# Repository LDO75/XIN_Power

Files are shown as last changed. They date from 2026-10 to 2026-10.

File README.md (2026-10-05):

# XIN Power

基于 **PY32F403 + SC8701** 的数控可调电源，面向当前 **V2补丁硬件**。

**3.2～32V · 0.1～8A过流设定 · 16点DAC校准 · 触摸屏 · 有线/蓝牙上位机**

最新控制版本为 **6.2.3**。本次开源打包修订标记为 **6.2.3-open.1**：设备协议/版本保持6.2.3，公开副本改用思源黑体生成的OFL字库，保留原交付包，二进制校验值与原6.2.3不同。

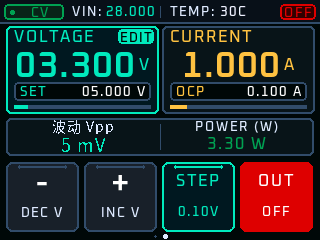
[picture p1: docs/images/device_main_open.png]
设备界面离线渲染预览


## 从这里开始

| 想做什么 | 入口 |
|---|---|
| 阅读完整开发文章 | [立创开源文章](docs/立创开源文章.md) |
| 查看当前硬件改动 | [V2补丁说明](hardware/README.md) |
| 编译、首次安装、升级 | [构建与下载](docs/构建与下载.md) |
| 做电压校准 | [校准与使用](docs/校准与使用.md) |
| 阅读开发顺序 | [开发历程](docs/开发历程.md) |
| 下载历史关键源码 | [历史版本索引](history/README.md) |
| 查看实际保护判据 | [当前固件说明](firmware/current/README_下载与校准.md) |
| 理解最新PI | [PI控制说明](firmware/current/docs/PI控制说明.md) |
| 实现自己的上位机 | [协议5](firmware/current/docs/WIRE_PROTOCOL_5.md) |
| 查看公开包验证结果 | [发布验证](docs/发布验证.md) |

## 当前完整工程

```text
firmware/current/
  01_Bootloader/     独立Bootloader（沿用5.9.3留存基准）
  02_Application/    当前APP、HAL/CMSIS、字库及生成工具
  03_Factory/        Bootloader与APP合并HEX脚本
  04_Recovery/       当前恢复路径说明
  05_PC_Tool/        Python/PySide6上位机、打包脚本、当前测试
  docs/             PI、协议、有线断链分析
  tests/            固件主机回归、界面渲染、RAM/栈预算
downloads/          开源构建APP/Bootloader/Factory、Windows上位机
hardware/           修改前V2原理图、补丁说明、外壳文件
history/            按版本排序的关键源码快照及校验信息
docs/               开源文章、开发历程、使用与编译说明
```

历史快照是本次整理后形成的归档，没有伪造原开发日期或把试验版统一称为实测稳定版。

## 硬件与功能边界

- R274=100kΩ；R314+R315=7.62kΩ；R316+R317=5.11kΩ；R292=1.8kΩ。
- 输出理想二极管MOS **D/S短接旁路**，软件按此状态适配。输出没有这一层防倒灌/隔离，关闭使能不等于物理断开端子。
- 8A是过流设定上限，软件不做恒流输出。输入过流阈值4.8A；没有完成32V/8A连续功率验证。
- INA读取目标500Hz，屏幕50Hz，常规回传默认25Hz；实际采样间隔需实测。
- “低频波动Vpp”是最近1秒采样极差，需要示波器另测高频纹波。
- 6.2.3仅在误差±100mV内PI微调；初始参数未完成实板带载整定。6.2.2历史节点可用于纯DAC控制对照。
- 原理图PDF为修改前参考，仓库尚未包含经过此次补丁更新的可编辑PCB/BOM/生产文件。

## 来源与许可

原电源方案参考立创开源作者 **cyxsnbb666** 的[Type-C可调电源项目](https://oshwhub.com/cyxsnbb666/typec-adjustable-power-supply-wi)。XIN Power由 **LDO75** 维护。

沿用本仓库现有 [GPLv3许可证](LICENSE)。第三方器件库及字体保留独立许可，详见 [THIRD_PARTY_NOTICES](THIRD_PARTY_NOTICES.md)。

## 反馈

报告问题时请注明：硬件阻值/输出级状态、固件与上位机版本、输入电源、设定和负载、万用表/示波器结果，以及故障现场。校准点和DAC读数对复现低压问题尤其有用。发布日志前请去除个人目录、设备标识或其他无关信息。

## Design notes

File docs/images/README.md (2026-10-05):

# 图片来源

- device_main_open.png、device_settings_open.png、device_settings_scroll_open.png：本次公开副本真实C端绘制代码的离线像素输出，中文采用XIN UI Heiti，不是实物照片。
- pc_smoke_623.png：原6.2.3 Qt离屏加载预览，不代表已连接设备或已实测回传速率。
- device_photo.jpg：开发者在讨论中提供的设备实物照片，拍摄于此次公开字体替换前，用于展示外观。
- off_oscillation_before_bypass.jpg：开发者提供的旁路前关断波动波形照片，只用于开发历程，不能用作当前旁路后的波形结果。

所有图像保留原始像素内容或由项目自身绘制代码生成，没有将离线渲染误标为实板验收。

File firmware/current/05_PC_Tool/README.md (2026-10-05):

# XIN Power Studio V6.2.3

运行EXE或run_windows.bat。左下角选择有线/无线、扫描系统端口、手动连接。扫描只枚举，连接只打开选定端口；旧协议4支持兼容文本，新版协议5二进制。

默认25Hz/40ms，可选10/5/50Hz。固件6.2.3修复了RATE设置不控制二进制遥测调度的问题。界面50Hz批量更新，中文状态日志显示最多5次/秒；完整收到的遥测仍写入记录及CSV。连接新版固件会配置40ms并读取STATUS，不更改电源输出。

Windows串口读写异常恢复同一有线端口，最多5次、每次间隔1.8秒，不重发旧的输出、设定或校准命令。改选端口/连接方式/断开取消恢复。普通命令确认超时会报告结果未知并继续接收数据。

校准16点，3.2–32V/0.1–8A，直接DAC调压，超过电流设定关断。校准保存和旧表迁移说明见根目录README_下载与校准.md。休眠在设备设置页选择。

当前版本测试（在tests目录）：python -X utf8 -m unittest test_620 test_622 test_623 -v。历史test_603等面向旧表/旧范围，不能直接作为本版验收。打包：build_windows.bat。
无硬件检查：XIN_Power_Studio_V6.2.3.exe --smoke-test --smoke-output preview.png，离屏启动并退出，不连接串口或启动实时控制接口。

新增全量程±100mV误差内PI微调，日志/诊断显示PI状态及误差；CSV29列。校准期间保持人工固定DAC；旧连续PID页面/接口不适用。控制参数及限制见根目录docs/PI控制说明.md。

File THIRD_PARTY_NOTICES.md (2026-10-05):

# 来源与第三方声明

## XIN Power

维护者：LDO75。沿用仓库已有GPLv3许可证，见根目录LICENSE。第三方文件的原有许可和版权不被根目录许可替代。

## 原电源工程参考

立创开源用户cyxsnbb666：[Type-C可调电源原工程](https://oshwhub.com/cyxsnbb666/typec-adjustable-power-supply-wi)。开发中参考其功率电路与STM32F1工程。当前公开目录是XIN Power的PY32工程及开发节点，没有重新打包原作者完整源码或替原作者选择许可。硬件参考图的来源关系在hardware/README及开发文章说明。

## 器件库

- Puya PY32F403 HAL和设备文件：保留各文件Puya/ST版权与BSD-3-Clause等原始声明；许可内容以文件头和所附文件为准。
- ARM CMSIS：保留Drivers/CMSIS/LICENSE.txt及相应文件版权说明。
- 上位机依赖PySide6/Qt、pyserial与Python：依赖库保留自身许可；requirements列出源码运行所需包，Windows可执行包的依赖通知按打包内容保留。

## 字体

- Oxanium：位图源自Oxanium，可重生成；原字体和OFL见02_Application/ThirdParty/Oxanium。
- 思源黑体：从Adobe官方source-han-sans的release提交`a4f7cf94edfb9d7ffbdfc4841de276358bd7e0f2`获取未修改的`SubsetOTF/CN/SourceHanSansCN-Regular.otf`。原字体及OFL见02_Application/ThirdParty/SourceHanSans。官方来源：[Adobe仓库](https://github.com/adobe-fonts/source-han-sans)、[OFL文本](https://github.com/adobe-fonts/source-han-sans/blob/release/LICENSE.txt)。
- 公开副本使用派生位图 **XIN UI Heiti**，由Tools/generate_heiti_font.py生成，派生位图仍适用OFL-1.1。没有把OFL字体更改为GPL许可。
- Windows SimHei只存在于原私有交付版本中；本次公开当前/相关历史副本的字库均替换为上述OFL派生位图，没有分发Windows字体文件。

历史节点添加的字体许可证和生成资源在索引中标注；保留原始包SHA256用于辨别本次公开整理与原交付快照的差异。

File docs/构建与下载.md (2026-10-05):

# 构建与下载

## 1. 工程顺序与工具

从`firmware/current`开始：01_Bootloader → 02_Application → 03_Factory → 04_Recovery说明 → 05_PC_Tool。

- 已使用工具链：Keil MDK / Arm Compiler 6.24；Puya.PY32F4xx_DFP.1.0.8；实际芯片PY32F403C1DT6，工程设备组PY32F403xD。
- Python 3环境；上位机依赖见05_PC_Tool/requirements.txt，安装pyserial和PySide6_Essentials。
- 字库重生成需Pillow；随源码提供OFL思源黑体、Oxanium字体及生成工具。
- 固件主机检查使用GCC和PowerShell；Keil链接后的RAM/栈预算需Python检查。离线检查不打开串口。

## 2. 内部Flash与外部Flash

| 区域 | 地址与长度 |
|---|---|
| Bootloader | 0x08000000，0x8000字节 |
| APP | 0x08008000，0x58000字节 |
| 内部Flash终点 | 0x08060000 |
| RAM | 0x20000000，0x10000字节 |
| W25暂存/回退 | 0x00000000 / 0x00080000，各0x80000 |
| 升级元数据 | 0x00100000 / 0x00101000，各4KiB |
| 设置/校准保留区 | 0x01FFC000～0x01FFFFFF |

独立Bootloader来自留存的5.9.3完整工程，升级布局/硬件ID/元数据schema沿用当前APP的兼容定义，比较结果见发布验证。未把旧Factory HEX当作新版本完整镜像。

## 3. 编译

已有Bootloader时只需要APP。在工程目录运行（按本机路径修改参数）：

```powershell
./build_firmware.ps1 -KeilPath 'C:/Keil_v5/UV4/UV4.exe' -Python python
```

也可分别用Keil打开：

```text
01_Bootloader/MDK-ARM/XIN_Power_BL.uvprojx
02_Application/MDK-ARM/XIN_Power.uvprojx
```

Bootloader输出`01_Bootloader/MDK-ARM/Objects/XIN_Power_BL.hex`；APP输出`02_Application/MDK-ARM/Objects/XIN_Power.hex`。APP脚本会检查零错误/零警告及栈预算。默认下载算法需选择官方器件包对应容量，不要用其他容量的通用算法代替。

公开中文位图已经生成。如需重生成：

```powershell
python 02_Application/Tools/generate_heiti_font.py
python 02_Application/Tools/generate_oxanium_font.py
```

## 4. 空片安装与APP更新

空片先生成完整合并HEX：

```powershell
python 03_Factory/make_factory_hex.py 01_Bootloader/MDK-ARM/Objects/XIN_Power_BL.hex 02_Application/MDK-ARM/Objects/XIN_Power.hex 03_Factory/XIN_Power_FACTORY_SWD.hex
```

脚本检查HEX校验、BL/APP地址、向量表及重叠。SWD首次安装下载Factory镜像，核对运行后再做校准。

**已有兼容Bootloader的板子只刷APP。** APP基址0x08008000，不覆盖前32KiB。保留W25Q256；不要为了升级执行全片擦除、修改读保护或CAL RESET。用上位机在线升级时选择APP HEX/BIN，等待上传、校验、应用和重启确认；BL搬运阶段保持供电。

## 5. 上位机源码和打包

进入05_PC_Tool，运行`run_windows.bat`，或安装requirements后按该脚本的Python入口运行。打包用`build_windows.bat`，其中PyInstaller等构建工具由脚本管理。

已有Windows EXE也放在downloads目录；与源码同为6.2.3。EXE不会因为本次固件换字体而自动修改通信版本。实时接口设置文件只在需要本机接口时使用，不含固定端口和个人会话数据。

## 6. 检查入口

```powershell
./tests/run_620_checks.ps1
```

上位机在05_PC_Tool/tests目录执行：

```powershell
python -X utf8 -m unittest test_620 test_622 test_623 -v
```

固件检查会产出UI像素预览和数据包向量，上位机测试使用它们。package_623.py为原交付包校验入口，其对原构建日志和文件布局有固定要求；开源包使用仓库发布说明及SHA256SUMS，不应直接套用原打包脚本声称验证通过。

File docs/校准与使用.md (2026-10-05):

# 当前版本校准与使用

## 首次使用

1. 按硬件补丁说明核对R316、R292及输出理想二极管旁路。
2. 使用稳定输入。28V PD供电要确认适配器与诱骗协议支持该档位；小电流自动休眠会影响调试。
3. 有线/无线手动选定系统串口，连接后核对固件6.2.3、硬件V2、协议5、3.2～32V范围。
4. 首先读取原校准表，不执行CAL RESET或全片擦除。
5. 新阻值/新输出通路下，空载用可信万用表重新确认各点，再接实际负载。

## 校准

16点：3.2、3.3、3.5、3.8、4、4.2、5、7.2、8.4、9、12、18、20、24、28、32V。

选择点位后手动调DAC。升压降低DAC码，降压提高DAC码；接近目标时单码调整。输入**万用表实测值**，点击采集并保存，等设备确认及读回一致后再继续。每个点独立生效，保存后输出关闭。

校准期间PI关闭，DAC固定。若DAC没有变化而万用表电压继续变化，先检查硬件工作点和参考供电，等待真实稳定再采集。没有“只要按钮成功就代表输出稳定”的假设。

schema5按名义电压迁移旧schema3/4匹配点。硬件标记0x4991对应当前阻值；不兼容阻值配置的表不能直接沿用。旧表12个匹配点可保留，新增3.2/3.5/3.8/4.2V需实测。

## 常用功能

- 主界面设定电压、过流阈值、开启/关闭输出；右滑进入左侧设置页。
- 超过电流阈值关断锁存，清除故障不会自动开启。
- 默认屏幕1分钟休眠，可选关闭/30/60/120/300/600秒；休眠不停止供电。任意触摸唤醒，下一次触摸才执行操作。
- 遥测默认25Hz；中文状态摘要最多5条/秒只是显示节流，实际数据以完整记录/速率统计为准。
- 输出关闭仍显示真实残压。Vpp是低频采样极差；切换设定后重新等待稳定并收集1秒窗口。

## PI边界

6.2.3在3.2～32V全范围、误差不超过±100mV时PI微调，超范围暂停并保持当前码。校准/换设定/关闭/故障会重置；只补偿INA测量点上的电压，不补偿该点之后的外部线损。

参数Kp0.20、Ki2.00/s、D0为待实板整定的初始值。DAC每码约14.33mV，不能承诺任意目标1mV精度。持续大于100mV的压降不在当前外环纠正范围。

## 实测建议

优先记录3.2/3.3/5V空载与加载/卸载，再扩展到12/24/32V。记录输入、负载、目标、万用表、电压波形、DAC和PI状态。短路/过流验收需量到真实电流及关断时刻，INA软件读取不能代替微秒级硬件比较器。高功率测试要同时记录输入限流与热状态。

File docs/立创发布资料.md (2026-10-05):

# 立创开源新项目发布资料

## 可直接填写

- 标题：**XIN Power｜PY32F403＋SC8701 3.2～32V数控可调电源**
- 摘要：基于PY32F403与SC8701的V2补丁电源，支持3.2～32V、0.1～8A过流设定、16点DAC校准、触摸屏、有线/蓝牙上位机和在线升级。本文公开完整工程及关键历史版本，记录低压调试、SRC供电漂移、输出级旁路、500Hz测量调度、二进制DMA通信和小误差PI微调的开发过程。
- 标签：数控电源、SC8701、PY32F403、INA226、Type-C、触摸屏、蓝牙、开源硬件。
- 源码链接：https://github.com/LDO75/XIN_Power
- 正文：[立创开源文章.md](立创开源文章.md)。
- 原项目来源：https://oshwhub.com/cyxsnbb666/typec-adjustable-power-supply-wi

## 附件对应

| 内容 | 仓库位置 |
|---|---|
| 当前完整源码 | firmware/current，或源码完整ZIP |
| APP/Bootloader/工厂HEX | downloads |
| Windows上位机 | downloads中的part1、part2及merge_pc_tool合并脚本；合并后为XIN_Power_Studio_V6.2.3.exe |
| 原理图PDF | hardware/V2_schematic_before_patch_2026-09-13.pdf |
| 必读硬件补丁 | hardware/README.md |
| 外壳模型 | hardware/enclosure |
| 历史关键源码 | history |
| 图片 | docs/images，caption需注明离线渲染或实物 |

原理图是修改前参考，平台若要求可生产PCB/BOM附件，当前材料尚未包含更新后的EDA工程、BOM、Gerber。不要把参考PDF上传成已修改完成的生产板文件。

## 图片顺序和图注

1. 设备主界面：离线执行真实LCD绘制代码的像素预览。
2. 中文设置页：公开OFL字库的离线预览，非拍摄照片。
3. 休眠/滚动设置：离线预览，标出休眠入口。
4. 上位机：Qt离屏加载预览，不作为实机通信/回传性能证据。

本次文章正文和附件在本地/GitHub准备后，平台项目是否已保存/发布，以真实项目链接和平台返回为准。没有项目链接时不能将“文档已准备”写成“已在立创发布”。

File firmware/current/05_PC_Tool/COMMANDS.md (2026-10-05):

# V6.2.0 命令

新上位机将操作编码为协议5二进制包；普通串口助手先发送INFO可进入兼容文本模式。完整字节约定见[通信协议](../docs/WIRE_PROTOCOL_5.md)。

| 操作 | 参数/行为 |
|---|---|
| INFO / STATUS / DIAG | 版本、状态、链路诊断，只读 |
| SET V mV | 3200–32000mV，已保存点映射DAC，无PID |
| SET I mA | 100–8000mA，过流关断阈值，无恒流环 |
| OUT ON / OFF | 开启/关闭；故障锁存时先CLEAR |
| CLEAR | 清除故障，保持输出关闭 |
| CAL POINT GET / GET id | 表概况/单点；schema5，id=0–15按电压升序 |
| CAL POINT START id | 手动DAC校准并开启输出，保留电流阈值 |
| CAL POINT STEP -5/-1/1/5 | 直接调码；负码升压、正码降压 |
| CAL POINT STATUS | 活动点/DAC/电压/ready，ready仅表示DAC已写入 |
| CAL POINT CAPTURE mV | 保存万用表值和DAC；先OFF再写Flash，上位机读回确认 |
| CAL POINT STOP | 关闭输出，恢复此前设定，不保存未采集数据 |
| CAL GET / RAW | 测量系数/原始读数 |
| CAL SET V/I gain offset / SAVE / RESET | 输出关闭时修改测量系数/保存/恢复默认；正常升级不要RESET |
| LOG ON / OFF | 遥测开关，故障事件仍回传 |
| LOG RATE 20 | 协议5固定20ms；文本兼容模式最短100ms |
| FW STATUS / BEGIN / DATA / END / APPLY / ABORT | 升级页管理，旧Bootloader兼容 |
| PING / HELP | 连通性/帮助 |

点位：3.2、3.3、3.5、3.8、4.0、4.2、5、7.2、8.4、9、12、18、20、24、28、32V。每个点独立保存后生效，不必全部完成。保存检查实测电压区间顺序和Flash写入，不以贴近目标或INA一致作为采集限制。

START所在通道持有校准，STEP/CAPTURE只允许该通道；其他通道可STOP或关闭输出。普通设定、测量校准、升级须先STOP，Flash忙时返回错误。超时不等于保存成功，应读取状态确认。

V6.2.0没有PID命令、恒流控制、独立低压SHORT判据。协议号36保留，当前APP不提供REBOOT命令。

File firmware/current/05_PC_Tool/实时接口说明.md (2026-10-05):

# V6.2.0本机实时接口

把realtime_settings.json（enabled=true）放在EXE旁边。仅监听127.0.0.1，启动后地址和随机令牌写入live_api.json；不会自动连接设备。请求需Authorization: Bearer令牌。

- GET /v1/state：最新解算遥测、数据年龄、设备信息、epoch。
- GET /v1/events?after=游标：完整遥测、ACK、错误、故障等增量事件。
- POST /v1/voltage：mv为3200–32000整数。
- POST /v1/output：on为布尔值。
- POST /v1/telemetry-rate：ms只能为20，固定50Hz。
- POST /v1/connection：connected为布尔值，只操作上位机当前选择的端口。

POST需当前epoch。HTTP202表示排队，不等于设备执行成功；需等待对应ACK和后续状态。手动校准期间不允许该接口修改普通输出或电压。PID接口在直接DAC固件不可用。

JSONL通过后台线程缓冲写入，实际路径以live_api.json的record字段为准。vfast为原始校准后电压，vraw为未校准电压，iraw为未校准电流，vpp为最近1秒低频波动，hz/maxgap为内部完整采样实测频率/间隔，seq/samplet为完整采样序号/时间。cegpio是MCU引脚读回，不是SC8701脚模拟实测；dw/dwt为成功DAC写入计数/时间。

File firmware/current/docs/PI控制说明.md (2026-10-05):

# 6.2.3小误差PI控制说明

## 用户确认的边界

范围3.2–32V；误差进入±0.1V才启用PID微调。实现采用PID的PI形式，D项0。测量点仍是现有输出INA226，不能补偿测量点之后的外部接线压降。正常起步使用现有16点校准映射，手动校准仍固定DAC。

| 状态 | DAC行为 |
|---|---|
| 开启输出/改设定 | 应用新的校准映射码，重置积分 |
| 有效新样本且误差≤100mV | PI微调，误差≤8mV时保持 |
| 误差>100mV | 保持已应用码，暂停PI；回到范围无突变恢复 |
| 样本失效或dt>20ms | 暂停PI、不把停顿时间累积进积分 |
| 关闭/故障 | 先关闭CE，再停车DAC；PI重置 |
| 手动校准 | 固定人工DAC，PI关闭，不自动学习/改校准表 |

## 方程与实现

e=设定电压−INA校准后快速电压（mV）。当地DAC斜率g（mV/码）用同一校准映射附近区间估计，端点用单边区间，无有效斜率则使用原电阻公式。

P=−Kp×e/g；I候选=I−Ki×dt×e/g；DAC连续命令=映射基准+I候选+P。负号对应本硬件DAC升高使输出降低。

Kp=0.20，Ki=2.00/s，Kd=0。每个新样本最多计算一次，目标500Hz，采样与限流判断先于PI。LCD绘制让出前台时也服务PI，无阻塞中断I²C。样本序号不变不重复积分。
进入误差范围时令I=已应用DAC−基准−P，防止比例项造成切换跳变。DAC裁剪到0–4095、连续命令限制在当前码±1内，再反算I；写入失败不提交积分。整数码需连续命令偏离当前至少0.65码才变化；写入至少间隔10ms，减少量化来回跳码。

按电阻理论每码约14.33mV，实际采用校准区间估计，不能承诺1mV调节分辨率。8mV死区和0.65码滞回用于限制噪声/量化引起的跳码，仍需实际噪声与负载验证。没有±100mV总补偿限制，只有用户指定的误差准入；DAC饱和时无法保证回到目标。

## 理论与模型的范围

把SC8701已经闭环的DAC到输出响应近似成归一化一阶G(s)=1/(1+τs)，软件PI为C(s)=Kp+Ki/s。连续模型特征式为τs²+(1+Kp)s+Ki=0，τ>0时这些参数满足二阶稳定条件；τ=200ms时阻尼约0.95。该推导不包含实际功率级的额外极点、轻载模式切换、采样/I²C延迟和MOS寄生。

真实C控制器另在216个离散一阶模型组合测试：3.2/17.6/32V，τ=5/20/80/200ms，纯延迟0/10/20ms，执行器增益0.5/1/1.5倍，±80mV负载扰动、±2mV测量噪声，加载后卸载。结果及最大末端误差见验证记录/model_summary_623.json；这是假设模型的结果，不是SC8701实机测量，不能据此承诺所有负载稳定或无过冲。

数字环路的采样和执行延迟限制可实现带宽；软件外环应根据实测动态调整，500Hz计算频率不代表500Hz控制带宽。参考：[Microchip数字控制实现](https://developerhelp.microchip.com/xwiki/bin/view/applications/power/digital-power-converter-basics/implementation-of-a-control-loop/)、[TI数字环路设计](https://www.ti.com.cn/cn/lit/pdf/slua622)。

正常PI写码使用同一映射基准作为Vpp调压事件标识，因此不会每次微调都清空1秒波动窗口。换设定、开关输出、手动DAC步进仍按原稳定准入冻结/重开窗口，PI本身的真实波动不会被普通微调事件隐藏。

## 建议实测记录

先在3.3V、5V、12V、32V分别观察空载、加载、卸载，记录vfast、误差、DAC、PI状态、波动和采样间隔。重点区分误差越过100mV导致的暂停与闭环参数振荡；前者是本版明确的准入规则。大于100mV压降不会自动纠正，不应靠提高Ki解决。参数未经过该板实测整定。

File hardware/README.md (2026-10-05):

# V2硬件基准与补丁

当前源码用于PY32F403C1DT6、SC8701、MCP4725/REF3030、LMV321、双INA226、W25Q256、ST7789/CST836的V2板。功率MOS曾与原作者不同，输出理想二极管MOS实装型号曾为AGM6014A；最终该级D/S被旁路。

## 最终基准

| 器件/网络 | 当前配置 |
|---|---|
| R274，Vout至FB | 100kΩ |
| R314+R315，FB至地 | 7.5kΩ+120Ω=7.62kΩ |
| R316+R317，FB至缓冲输出 | 4.99kΩ+120Ω=5.11kΩ |
| R292泄放 | 实装1.8kΩ |
| DAC | 3.000V参考，4096码比例 |
| 输出理想二极管 | MOS D/S短接旁路，当前功率通路不依赖此级 |

早期曾从输入28V向MX16171的SRC飞线供电，用于解决输出侧供电下的低压/漂移问题。这是历史排查方案，不是当前版本必须保留的供电要求。旁路之后应避免仍连接控制器的残留供电/栅极网络干扰其他节点；具体拆改以实板连线为准。

## 图纸和外壳文件

- [V2修改前原理图](V2_schematic_before_patch_2026-09-13.pdf)：来源为开发者提供的2026-09-13 PDF。R316、R292及输出级请以上表和实装为准。
- [外壳目录](enclosure/)：开发者提供的STEP与3MF，文件保留原中文名称。打印材料、尺寸公差、散热开孔和端子位置需根据实物确认。

本次已收集到原理图PDF及外壳模型；**未收集到完成当前补丁的可编辑EDA工程、BOM和Gerber**。因此这些文件不能作为“已完成生产包”使用。

## 输出关断与反向供电

CE关闭的是SC8701功率级。输出电容和板内供电/测量路径仍可能留下残压，固件回传实际测量值，不把关闭状态强制显示为零。旁路后的输出缺少原理想二极管提供的反向隔离；外部电池、另一个带电电源、并联输出需要专门的隔离/反向保护设计。

## 理论DAC关系

Vout=Vfb(1+Ru/Rd+Ru/Ri)−Va·Ru/Ri。按Vfb=1.22V估算：

- 4.99kΩ配置：Vout≈41.10−19.57Va，每码约14.33mV。
- 7.5kΩ配置：Ri=7.62kΩ，Vout≈33.24−13.12Va，每码约9.61mV。

这只表示反馈网络的直流数学关系，不能证明运放共模范围、功率级动态或输出后级都正常。更换阻值后需重校，不能混用旧硬件标记的DAC表。

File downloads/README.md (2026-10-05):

# 当前公开构建下载

## 6.2.3-open.1

设备仍报告6.2.3/协议5。本次公开APP使用思源黑体派生位图，与原6.2.3私有交付镜像HASH不同，控制参数/硬件基准不变。

| 文件 | 用途 |
|---|---|
| XIN_Power_V6.2.3_OPEN1_APP_USB_BT.hex / .bin | APP，基址0x08008000，已有Bootloader时选它 |
| XIN_Power_BL_BASE_5.9.3.hex | 留存5.9.3基准Bootloader在公开目录重新编译的镜像 |
| XIN_Power_V6.2.3_OPEN1_FACTORY_SWD.hex | 本次Bootloader与APP合并，空片SWD首次安装 |
| XIN_Power_Studio_V6.2.3.part1 / .part2 | 原6.2.3 Windows上位机的两个分卷，与当前协议兼容 |
| merge_pc_tool.cmd / merge_pc_tool.ps1 | 合并分卷，生成并校验 XIN_Power_Studio_V6.2.3.exe |
| XIN_Power_V6.2.3_OPEN1_FullSource.zip | 当前完整工程、构建脚本与许可；与源码目录对应 |
| SHA256SUMS.txt | 本次下载文件校验 |

GitHub文件页面点击Download raw即可下载。已有BL只更新APP，不要全片擦除。完整说明见docs/构建与下载及发布验证。

Windows上位机：下载 `.part1`、`.part2`、`merge_pc_tool.cmd`、`merge_pc_tool.ps1`，放在同一个文件夹，双击 `merge_pc_tool.cmd`。合并结果的SHA256必须是 `26b0bc8aff796a220c3d64fe7aa41e574d7a40b57a84bfd3dafa50d0bbba67cf`。分卷仅用于绕过上传接口的单次传输限制，合并后的程序与原交付EXE完全一致。

Windows程序基于Python3.12、PySide6/Qt6.8.3、pyserial3.5及PyInstaller6.16打包。依赖许可文本在licenses；上位机源码和打包脚本可用于重建/替换依赖，Qt源代码入口为https://code.qt.io/qt/。本次上传没有重新运行实机串口。

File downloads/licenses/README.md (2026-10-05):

# Windows上位机依赖许可

本次WindowsEXE沿用6.2.3交付，源码与构建脚本在firmware/current/05_PC_Tool。

| 组件 | 版本/来源 | 许可及源码入口 |
|---|---|---|
| Python | 3.12.7，打包构建环境 | Python-3.12-LICENSE.txt；https://www.python.org/downloads/source/ |
| PySide6 / Shiboken6 / Qt | 6.8.3 Essentials | LGPL-3.0.txt及GPL-3.0.txt；https://code.qt.io/pyside/pyside-setup/；https://code.qt.io/qt/ |
| pyserial | 3.5 | pyserial-LICENSE.txt；https://github.com/pyserial/pyserial/tree/v3.5 |
| PyInstaller | 6.16.0 | pyinstaller-COPYING.txt，含Bootloader例外；https://github.com/pyinstaller/pyinstaller/tree/v6.16.0 |

许可文本分别从构建环境、GNU官方许可页面和上述版本的PyPI源码分发包取得。可通过公开上位机源码及PyInstaller打包脚本重新构建并替换库；完整许可条件以各文本为准。运行程序不代表许可变更。

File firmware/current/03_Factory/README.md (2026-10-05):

# 首次安装合并HEX

先编译01_Bootloader和02_Application，再运行make_factory_hex.py。地址、校验和、向量表和重叠检查通过后才会生成Factory镜像。

已有Bootloader只更新APP；Factory用于空片首次SWD安装或明确需要重装的情况。不要为了普通升级清空W25Q256或已有校准。

公开包downloads中的Factory来自本次重建BL及思源字库APP合并。文件检查通过不等于实机首次安装/掉电恢复已验收，详见docs/发布验证.md。

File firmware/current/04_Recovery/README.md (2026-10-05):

# 恢复入口

已有Bootloader时使用当前APP；空片使用03_Factory合并脚本。历史5.8.6恢复HEX对应旧硬件和旧存储格式，不作为当前V2补丁板的默认恢复镜像。故障记录和校准数据应先备份。

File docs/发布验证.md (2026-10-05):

# 6.2.3-open.1公开副本验证

本次只整理、构建和验证公开副本，没有连接电源串口、烧录或执行负载试验。原6.2.3交付包保留。

## 本次副本差异

- 中文位图由Windows SimHei改成OFL思源黑体派生的XIN UI Heiti；提供原字体、许可、固定上游提交、生成脚本和派生位图声明。
- 补入留存5.9.3基准Bootloader完整源码及工厂合并脚本；APP/BL的OTA布局文件去除换行形式差异后完全一致。
- 当前完整工程按01～05目录提供；第三方Oxanium资源和许可补齐。
- 历史关键节点公开归档标明原始包/公开包HASH、硬件前提及整理差异。6.2.2同样换OFL中文位图后重新构建；其他节点提供留存的对应APP。
- 未修改6.2.3控制逻辑、保护阈值、协议5字段或校准存储布局。设备版本仍为6.2.3，文件名OPEN1用于区别公开构建。

## 已完成

| 检查 | 结果 |
|---|---|
| 当前APP完整Keil重编译 | 0 errors / 0 warnings |
| 当前Bootloader重编译 | 0 errors / 0 warnings |
| Keil项目引用完整性 | BL、APP全部FilePath在公开完整源码内可解析 |
| APP RAM/栈预算 | RAM55376/65536；栈8192；静态最大3620；另留2048后余量2524 |
| 公开APP图像 | 126992字节；基址0x08008000；包含6.2.3/proto5标识 |
| 工厂合并 | BL/APP地址、HEX校验、向量表和非重叠检查通过 |
| 当前固件C回归 | 校准/迁移/Flash、保护/优先电流、500Hz新样本、协议/DMA/重试、Vpp、UI清黑/休眠及PI边界通过 |
| 假设一阶模型 | 原控制器216组组合通过；未扩展为实际SC8701电路模型 |
| 当前上位机源码检查 | test_620/test_622/test_623，共19项通过 |
| 思源中文界面 | 重新渲染并目视检查设置页，文字、布局与按钮正常；切页/休眠回归通过 |
| 6.2.2公开副本 | Keil零错误零警告、C回归通过；纯DAC对照节点 |
| 全部公开ZIP | ZIP校验通过，含逐文件SOURCE_SHA256 |

APP SHA256：`5a403d5a24ecfcac26b74bdd554b5de0ee46a06ca9b34f3953439dbce5b1ba1c`。

Bootloader从留存工程重新构建。Factory只是本次重建镜像的地址检查与合并，没有据此宣称空片首次下载、升级搬运掉电或回退全过程经过本轮实机验收。上位机EXE沿用原6.2.3交付，源码测试本轮重新运行。

## 仍需实测

- 3.2/3.3V启动、加载/卸载、DAC量化波动、PI整定及过冲恢复。
- 输入限流条件下的输出功率、持续温升、不同负载的稳定性。
- 真实短路/过流关断延迟、板上CE相关电路和功率级硬件响应。
- 同时切页、触摸、通信时的最大采样间隔及25Hz回传达标情况。
- 理想二极管旁路之后的关断残压及外部反向供电路径。

离线模型、渲染和源码检查验证实现及边界行为，不能替代以上测量。静态RAM/栈预算也不是实机高水位测量。

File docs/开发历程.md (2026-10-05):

# 开发历程与版本边界

按实际留存的发布记录及开发者实板反馈整理。表格描述阶段目标，不把一次离线检查或一次空载校准当成全面验收。未恢复到的更早版本和中间小修订不虚构源码节点。

| 版本/阶段 | 变化与原因 | 当时边界 |
|---|---|---|
| 5.8.6恢复参考 | 早期SWD恢复文件、旧上位机 | 旧硬件/存储前提，不是当前默认恢复包 |
| 5.9.3 | 留存完整BL、APP、Factory、Recovery、PC；风扇迟滞和通信调度改进 | 原输出控制，尚未完成后来的低压/输出级修改 |
| 5.9.4～5.9.9 | 在既有升级、校准与通信框架上连续迭代 | 留存记录可追溯，此次未把每个小版本都打包 |
| 6.0.0～6.0.1 | 低压启动与16点校准，增加3.6/3.9/4/4.5V等点 | 仍有稳定和保存门槛；低压异常待定位 |
| 6.0.2 | 加强校准稳定窗口/漂移判定 | 使用复杂，产生校准难保存的反馈 |
| 6.0.3 | 直接人工DAC→实测值→保存→插值 | 按当时要求主要保留过流；不作为当前保护完整版本 |
| 6.0.4 | 修复3.6V点被旧DAC顺序校验拒绝保存 | 低压跳变仍需排查硬件 |
| 6.0.5 | 持续PID试验 | 为比较响应而做的试验版 |
| 6.0.6 | 上位机PID参数页 | 参数需在稳定输入、明确负载条件下整定 |
| 6.0.7 | 本机实时读取/控制接口 | 便于调参；本次未把此试验节点作为默认公开控制版 |
| 6.0.8 | R316=4.99kΩ、直接DAC映射；SaveDiag/SaveFix1/UIFix修复Flash保存、读回、上位机协调 | 同一版本号下有多个诊断/修复变体，本次选SaveFix1_UIFix |
| 6.1.0 | 输出理想二极管SRC输入侧供电补丁 | 关闭残压与规律波动仍有实板反馈 |
| 6.1.1 | 2～32V、R316=7.5kΩ，恢复基础保护 | 2V校准空载触发SHORT的判据有问题 |
| 6.1.2 | 短路资格判定修正 | 继续排查误判 |
| 6.1.3 | 短路改走同一立即过流路径，去掉低电压独立SHORT判据 | 有效电流越限关断，仍依赖采样时延 |
| 6.1.4 | 目标1kHz读取 | 实板触摸和刷新受影响，后续调整为500Hz |
| 6.1.5 | R316=4.99kΩ匹配理论DAC与硬件标记 | 当时2～32V/17点设计不是当前最终范围 |
| 6.2.0 | 最终3.2～32V、8A设定；500Hz采样/50Hz屏幕；16点；协议5、DMA、中文设置与PC重排 | 输出级仍处于随后调整的阶段；回传默认随后改25Hz |
| 6.2.1 | 输出理想二极管MOS D/S旁路；切页清黑/顶部栏恢复；Vpp换设定后重建窗口 | 开关仍是CE使能，不是物理输出隔离 |
| 6.2.2 | 屏幕休眠、回传25Hz、RATE生效、有线同端口恢复 | Windows访问拒绝的设备/驱动根因未唯一定位 |
| 6.2.3 | 全量程±100mV误差内PI，死区、滞回、单码节流、积分和门控切换处理 | 最新试验参数有离线模型/代码检查，尚待带载整定 |
| 6.2.3-open.1 | 本次公开目录、文档、历史索引、OFL中文字体及重建镜像 | 控制/协议仍6.2.3；字体不同，二进制HASH不同 |

## 四条调试主线

### 校准

从“目标/稳定条件限制”回归“人工DAC与万用表实测关系”。随后修复单点资格、Flash保存、读回、上位机显示以及不同schema/点位ID迁移。R316变更必须同步曲线标签。

### 低压硬件

3.5V附近跳变 → 分段观察前后电压 → 反馈阻值与DAC表匹配 → SRC供电方式改变后漂移不同 → 断开SRC周期波动消失 → 最终旁路该输出级。用户提供的测量支持缩小故障范围，没有证明理想二极管芯片内部唯一机制。

### 保护与调度

误判低电压空载SHORT → 以实际过流为短路关断依据 → 保留输入欠压/过压/过温/监测失联 → 1kHz影响交互 → 500Hz采样、电流优先、SPI让出服务、DMA发送。

### 产品交互

屏幕主界面精简 → 设置页中文 → 清黑/顶栏重绘 → Vpp稳定后重新统计 → 屏幕休眠不改变输出 → PC手动选连接方式、中文日志、后台批处理 → 默认25Hz与有限同端口恢复。

## 最新验证的解读

离线C检查覆盖保护、存储、协议、重试与UI状态；Python检查覆盖数据包、命令、升级状态机、串口选择/恢复和页面加载。假设一阶模型用于验证控制实现的边界行为，不是实际SC8701/MOS电路的SPICE模型。

实板曾完成不同节点的校准与低压观察；最新公开字体构建没有因此被标为“完成32V8A、所有负载、长期老化验收”。当前范围和硬件状态请以README/硬件补丁为准。

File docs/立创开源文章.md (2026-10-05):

# XIN Power：从低压调试到完整软硬件闭环的 3.2～32V 数控电源

> 基于 PY32F403 与 SC8701 的 V2 补丁硬件项目，支持触摸屏、有线/蓝牙上位机、16点电压校准、过流关断、在线升级，以及小误差区间的 PI 电压微调。本文记录当前方案，也保留开发过程中走过的弯路。

## 一、为什么做这台电源

做单片机和各种小板子时，最常用的功能其实很直接：设定电压、限制异常电流、观察功率，出问题时及时关闭输出。3.3V尤其重要，因为这正是很多单片机的工作电压。

XIN Power的开发经历了多轮固件、上位机和硬件修改。最耗时的问题集中在低压区：3.6V校准时，输出从约3.5V突然跳到4V；部分阻值配置下，2V目标始终降不下来；关闭输出后，还能看到规律性的小幅电压波动。期间尝试过直接DAC映射、连续PID、反馈电阻调整、理想二极管供电修改，以及采样和任务调度优化。

最后根据当前V2板子的实测表现，把公开版本的调压范围确定为 **3.2～32V**，电流设定上限 **8A**。这个取舍保留了3.3V应用所需的低压区，也让软件参数与当前硬件保持一致。

项目在原开源电源方案的基础上继续开发。原项目作者为立创开源用户 **cyxsnbb666**，原工程链接：[Type-C可调电源原项目](https://oshwhub.com/cyxsnbb666/typec-adjustable-power-supply-wi)。感谢原作者提供功率级设计和源码参考。XIN Power的PY32工程、上位机、校准流程及后续补丁在此基础上迭代，第三方器件库和字体保留各自许可声明。

完整源码与版本索引：[LDO75/XIN_Power](https://github.com/LDO75/XIN_Power)。

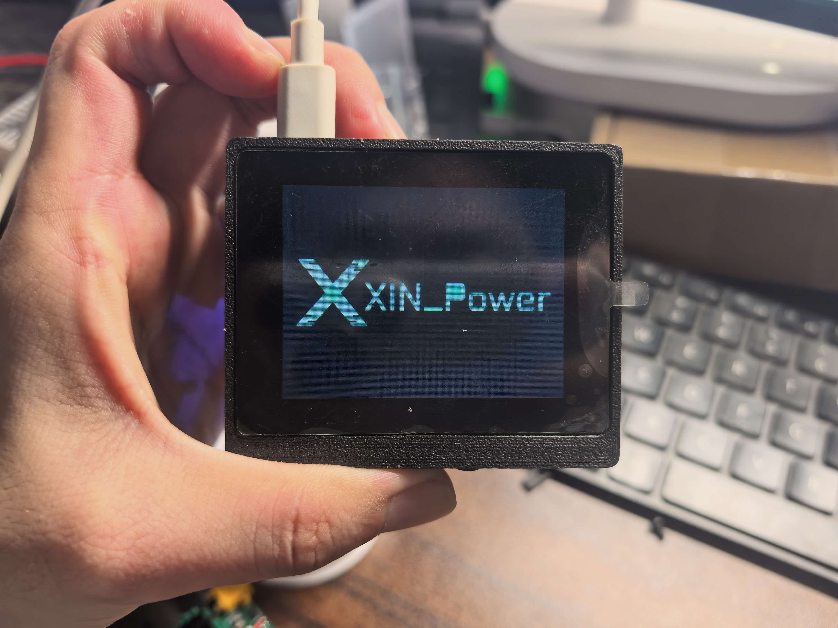
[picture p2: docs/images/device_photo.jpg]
开发中的XIN Power实物外观


*开发者提供的实物照片，拍摄于公开字体替换前。*

## 二、当前版本能做什么

| 项目 | 当前方案 |
|---|---|
| 主控 | PY32F403C1DT6，V2硬件 |
| 功率级 | SC8701四开关同步升降压 |
| 输出设定 | 3.2～32V |
| 电流设定 | 0.1～8A，越限关断并锁存 |
| 调压 | MCP4725 DAC、LMV321缓冲、FB注入网络 |
| 电压校准 | 16点实测DAC曲线，点间线性插值 |
| 测量 | 输入、输出各一颗INA226 |
| 调度目标 | INA新样本500Hz，屏幕50Hz，常规回传25Hz |
| 显示 | 电压、电流、低频波动Vpp、功率；中文设置页 |
| 屏幕休眠 | 可设置时限，关闭背光并置黑，输出和保护继续运行 |
| 通信 | 有线串口、经典蓝牙SPP；协议5二进制包和UART DMA发送 |
| 存储及升级 | W25Q256保存校准、设置和升级镜像；独立Bootloader |
| 最新控制版本 | 6.2.3，全量程±100mV误差内的PI微调 |

**8A是设定上限。** 当前代码同时保留4.8A输入过流阈值，因此28V输入时对应约134.4W输入功率，输出还要扣除转换损耗。没有完成32V、8A连续输出的热与功率验证，不能把两个量程端点相乘作为已验证输出功率。

这个版本的“限流”采用过流关断方式，软件没有实现恒流输出。用于需要恒流充电、电子负载或电池管理的场景时，应另行设计相应控制环和保护方案。

## 三、系统结构

系统可以分为功率通路、调压通路、测量通路和交互通路。

```text
输入电源 → SC8701四开关功率级 → 输出测量与端子
                ↑ CE使能              │
                ↑ FB                  ↓
PY32 → MCP4725 → LMV321          输出INA226
  │                                 │
  ├─ 输入INA226、NTC                 │
  ├─ W25Q256校准/设置/升级            │
  ├─ ST7789屏幕、CST836触摸           │
  └─ 有线/蓝牙上位机 ←───────────────┘
```

SC8701负责功率级内部闭环，单片机通过DAC调整反馈网络的工作点。INA226提供外部测量，单片机先判断电流保护，再处理其他控制和交互任务。最新PI属于功率级已有闭环外面的慢速微调环。

SC8701的器件能力可参考[南芯官方资料](https://cn.southchip.com/upload/file/SC8701_datasheet_brief_cn.pdf)。整板可用范围仍由具体反馈网络、器件供电、MOS、布局、热设计和固件共同决定。

### 当前V2补丁硬件基准

| 位置 | 实装/处理 |
|---|---|
| R274 | 100kΩ |
| R314、R315 | 7.5kΩ、120Ω，合计7.62kΩ |
| R316、R317 | 4.99kΩ、120Ω，合计5.11kΩ |
| R292 | 1.8kΩ输出泄放 |
| DAC参考 | 3.000V |
| 输出理想二极管 | MOS的D/S已短接旁路，后续软件按此适配 |

仓库中的2026-09-13原理图是**修改前的V2参考图**，必须结合硬件补丁说明阅读。它没有被标成已经修改完成、可以直接照图生产的新PCB版本。外壳STEP及3MF文件也一并提供，装配尺寸需结合实物核对。

## 四、调压公式和校准为什么要分开

反馈节点的直流关系可以先用KCL估算。设上拉电阻为Ru、对地电阻为Rd、DAC注入电阻为Ri，缓冲器输出为Va，正常闭环的FB电压为Vfb，则：

```text
(Vout − Vfb)/Ru + (Va − Vfb)/Ri = Vfb/Rd
Vout = Vfb × (1 + Ru/Rd + Ru/Ri) − Va × Ru/Ri
```

按当前电阻及代码使用的Vfb=1.22V，Vout约为41.10−19.57×Va。DAC以3V、4096码比例估算，每增加一码，输出约降低14.33mV。这解释了两个现象：升高输出电压需要降低DAC码；显示可以按mV给出数值，但物理执行器没有1mV一步的分辨率。

这里的公式假设缓冲器在线性区、FB正常闭环、后级没有额外异常。它适合提供初值和斜率，不能替代实物校准。特别是低压区需要更高的DAC注入电压，还需要核对运放输入共模和输出摆幅。LMV321并不能只凭“输出接近电源轨”这一项就保证所有输入点位正常，可参考[TI官方数据手册](https://www.ti.com/lit/ds/symlink/lmv321.pdf)。

### 当前16点校准

点位按电压升序排列：

**3.2、3.3、3.5、3.8、4.0、4.2、5、7.2、8.4、9、12、18、20、24、28、32V。**

低压区更密，是为了给3.3V附近留下足够的实测信息。高压区变化相对平滑时，采用更稀疏的点位。

流程为：选点 → 手动微调DAC → 等待万用表读数稳定 → 输入实测电压 → 采集并保存 → 读回核对。

每个点独立保存并立即参与映射，不需要全部16点完成后才能使用。正常输出根据已保存的“实测电压—DAC”关系插值。手动校准期间固定人工DAC，PI暂停，避免把正在自动移动的执行器当成固定校准点。

旧表按名义电压迁移，不按旧点位ID直接套用。阻值改动后，旧DAC曲线可能不再适用；更换R316后必须核对硬件标记和校准表。没有可靠实测点的区间也不能被宣称已经精密校准。

## 五、低压问题的完整排查过程

### 1. 校准流程曾经太复杂

早期版本在校准中加入了稳定窗口、漂移门槛、靠近目标才能保存等条件。实际使用时出现“已经调到目标，仍不能采集”的情况。后续回到更直接的方式：人工调DAC，输入万用表实测，保存对应关系。

这次调整明确了校准和保护的职责。校准解决测量及映射关系；越限关断解决异常供电。保存成功还必须由设备确认、Flash写入和读回核对共同证明，单凭上位机按钮变色不够。

### 2. 连续PID没有直接解决所有低压异常

6.0.5～6.0.7尝试持续PID，并增加实时参数和读取接口。调试中还遇到PD电源在长时间小电流时休眠、人工关断影响阶跃记录等情况。这些都会改变试验条件。

更关键的是，输出级异常、供电漂移和反馈电阻不匹配都不是单纯提高或降低PID参数就能修复的。参数整定需要先确认输入稳定、测量可信、执行器工作正常，然后根据阶跃和加载/卸载响应调整。

### 3. R316影响可调范围，也影响旧校准表

把R316从7.5kΩ改为4.99kΩ，改变了DAC对FB的注入增益。软件必须同时修改理论参数和曲线标记。仅换电阻、仍使用旧映射，很容易出现预置DAC码不合适、低压区异常或校准点失准。

当前公开版本固定R316=4.99kΩ。历史7.5kΩ版本仍作为开发记录保存，其固件不适合作为当前补丁板的默认下载版本。

### 4. 理想二极管的供电成为关键线索

实板排查中发现：理想二极管前后的表现不同；SRC从输出侧经原RC供电时，固定DAC下电压会缓慢上升，约一分钟后趋于稳定，需要人工调整至少10码才能抵消。改为输入侧28V直接供电后，用户报告缓慢漂移消失，低压校准也恢复正常。

另一组观察是关闭输出时出现约0.98Hz的周期波动。改变SRC供电方式，波动幅度会变化；断开SRC后该现象消失，前端和后端残压也明显降低。这些结果把排查重点指向输出理想二极管及其与前级的交互。

这些是实板观察，能支持“该级参与了异常”的判断。它们还不足以单独证明MX16171内部某个具体保护状态、某种MOS寄生参数或某个固定阈值就是唯一根因。期间的简化模型用于研究可能的充放电和启停机制，不应写成芯片内部电路已经被准确仿真。

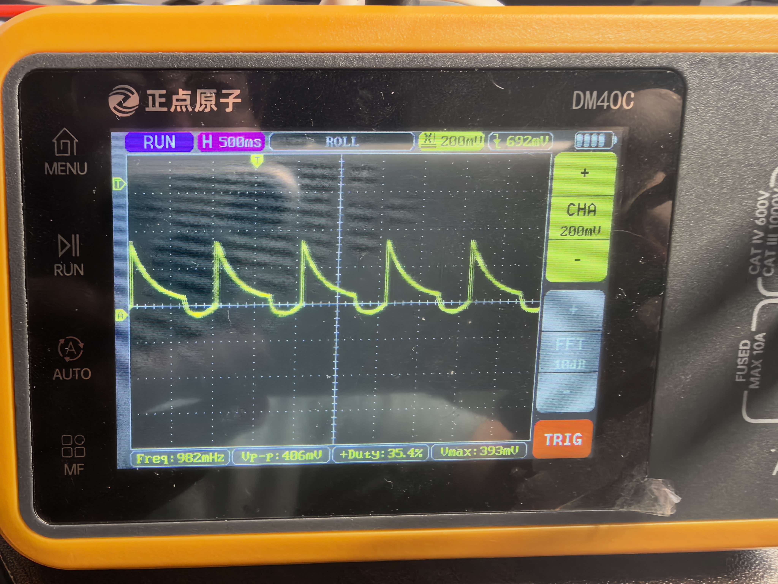
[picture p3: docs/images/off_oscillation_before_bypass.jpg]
输出级旁路前的关断波动观察


*开发者提供的历史波形照片：约0.98Hz，图中Vpp约406mV。此图对应旁路前的排查阶段。*

### 5. 最终旁路输出理想二极管

当前板把输出理想二极管MOS的D/S短接旁路，后续软件按这个状态适配。这样避免继续依赖该级的低压工作和供电行为。

这项修改也改变了功能边界：输出端失去这一层防倒灌和隔离能力，软件“关闭输出”控制的是SC8701使能，不能据此承诺端子被物理断开。接外部带电电源或电池、并联其他电源等用途需要重新设计输出隔离，不能沿用原理想二极管的功能描述。

## 六、保护逻辑：先看电流，再处理其他事情

有一次空载低压校准触发SHORT，日志显示电压很低，电流也只有接近零的微小数值。问题出在把“低电压状态”当成独立短路依据。后续去掉这一判断，让短路大电流走同一过流关断路径。

当前软件保护如下：

| 保护 | 当前判定 |
|---|---|
| 输出过流 | 大于用户设定，首个有效越限电流读数关断；8.5A绝对备用阈值 |
| 输入过流 | 大于4.8A，首个有效越限读数关断 |
| 输入欠压 | 小于4V持续200ms |
| 输出绝对过压 | 大于33V |
| 输出相对过压 | 高于参考+max(300mV，参考的10%)持续100ms |
| 过温 | 有效温度达到80℃ |
| 监测失联 | 输出开启时完整新样本持续中断500ms |

故障关断锁存，清除故障后仍保持关闭，需要人工重新开启。手动DAC校准暂停相对过压判断，但绝对过压、电流、温度和监测失联等仍保留。降压过程的过压参考按泄放RC估算下降，避免正常放电被旧目标与新目标的差值误判。

显示电流会扣除板内泄放电流并做零点修正；保护使用扣除泄放前的电流，避免显示修正掩盖真实越限。软件保护依赖INA的转换、I²C读取和调度延迟，不能被描述成微秒级硬件短路比较器。模拟功率级和板上CE相关电路的响应还需分别测量。

## 七、为什么采样500Hz、屏幕50Hz、回传25Hz

曾经把INA轮询提高到1kHz后，实板出现触摸与屏幕刷新失效。最终把三类任务分别确定为：

- 测量与电流判断：目标2ms一次，即500Hz。
- 屏幕刷新：目标20ms一次，即50Hz，主要更新变化区域。
- 常规回传：默认40ms一次，即25Hz。

INA226采用连续母线/分流转换，各332µs、平均1次，只有确认新转换完成才计为新样本。转换时间可参考[TI INA226数据手册](https://www.ti.com/lit/ds/symlink/ina226.pdf)。500Hz是软件调度目标；实际最大样本间隔仍受总线、LCD、Flash等工作影响，需要记录实测。

屏幕分段传输时继续服务采样。串口发送使用DMA，遥测拥塞时丢弃整帧，下一周期发送最新状态，避免旧遥测挤占控制任务。

协议5发送实际二进制字节，采用同步头、类型、长度、序号和CRC16。常规遥测载荷77字节，整帧87字节。25Hz对应2175字节/秒，115200、8N1时约占19%的线速。上位机解包后显示中文状态，不需要用户逐行阅读英文原始报文。

通信还增加了同序号去重，防止命令重试把“DAC步进一步”或“保存一次”执行两次。有线读取异常时尝试恢复同一端口，重连后读取真实状态，不重放之前的开启、调压或校准操作。

此前Windows曾返回串口“拒绝访问”错误。回传频率和恢复逻辑已经修改，但设备、驱动或电气层面的断链根因尚未被唯一定位，因此这里不会把25Hz描述成对所有USB断链的彻底修复。

## 八、设备界面和上位机

主界面保留调压、过流阈值和输出开关。中间栏左侧显示低频波动Vpp，右侧显示功率；移除使用率低的波形页，以及主界面的Ah/Wh累计显示。

Vpp取最近1秒有效电压样本的最大值减最小值，使用未经过显示低通的校准后电压。换目标时暂停并重新建立统计窗口，稳定后再更新，避免把正常升降压过程算作纹波。正常PI的小幅变化仍进入统计，真实波动不会因每次调码而被隐藏。500Hz采样无法代表开关频率纹波，测高频纹波仍需要示波器。

切页时先全屏清黑，再绘制新页面。返回主界面强制重画顶部栏，局部数字刷新恢复一致的背景。用户反馈残影已有明显改善；清黑处理遗漏像素，液晶物理残留或反光则需要另行辨别。

中文设置页提供亮度、蜂鸣器、方向、零点校准、休眠和版本信息。公开发布副本使用OFL授权的思源黑体生成字库，派生位图名为XIN UI Heiti，保留黑体风格。

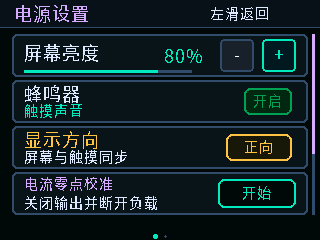
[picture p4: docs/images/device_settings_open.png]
公开副本中文设置页


*真实C端绘制代码的离线像素预览。*

休眠时间可选关闭、30秒、1分钟、2分钟、5分钟、10分钟，默认1分钟。休眠时关闭背光、清屏为黑，电源输出、测量、保护和通信继续。触摸任意位置唤醒当前页面，整次唤醒手势被消耗，避免唤醒时误触调压或输出按钮。

上位机把连接方式、端口、扫描、连接状态和版本信息集中到左下角。扫描仅枚举系统串口，用户手动选择有线或无线，程序不会自动切换到蓝牙。后台解包、记录数据，界面批量刷新；可见状态日志做节流，完整记录仍保留实际收到的数据。

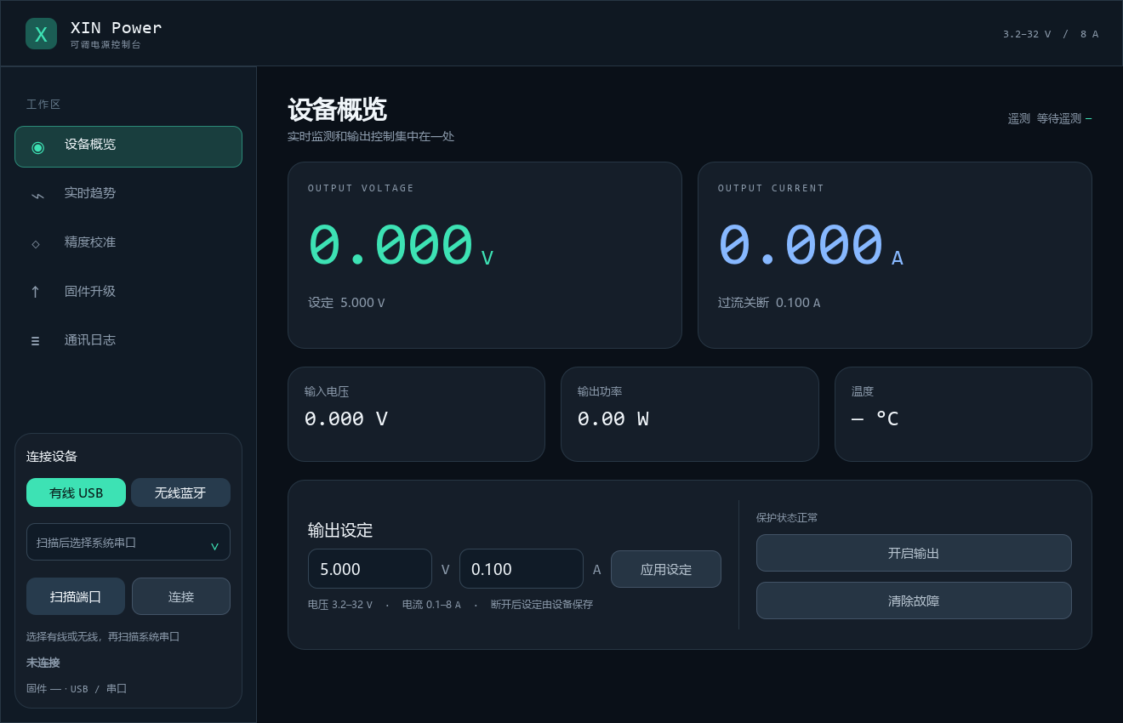
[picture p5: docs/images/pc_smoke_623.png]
XIN Power Studio上位机预览


*Qt离屏预览，未连接实机。*

设备与上位机截图见仓库[界面图片目录](https://github.com/LDO75/XIN_Power/tree/main/docs/images)。图片中离屏渲染和实物照片分别标注，渲染预览不作为实机性能证据。

## 九、6.2.3为什么增加小误差PI

DAC校准映射解决静态工作点，负载变化后仍可能出现小幅压降。6.2.3在整个3.2～32V范围内增加PI微调，但按照本次需求，只有实测误差进入±0.1V后才工作。

```text
正常开启：应用校准映射DAC
误差≤100mV：PI微调
误差>100mV：暂停PI，保持已经应用的DAC
重新进入范围：无突变地恢复积分
手动校准、关闭或故障：停止/重置PI
```

这里的±100mV是**启用条件**，没有被实现成总补偿幅度限制。如果负载造成的压降超过100mV且前级不能自行回到范围，当前控制不会主动追赶。调整Ki无法绕过这一明确的准入规则。

初始参数为Kp=0.20、Ki=2.00/s、Kd=0。每个新样本按实际时间间隔积分；8mV死区、DAC决策滞回、至少10ms写码间隔及单次最多一码，用于抑制测量噪声和12位量化来回跳码。饱和时处理积分，写入失败不把未执行的动作当成已经执行。

把前级响应近似为一阶系统时，可以推导外环的稳定条件，也做了216组不同时间常数、延迟、增益、加载/卸载和噪声组合的模型检查。但实际SC8701轻载模式、额外极点、MOS寄生和布局并未被完整纳入。**这套PI参数仍需实板带载整定**，模型通过不能承诺任何负载都无过冲。需要纯DAC对照时，可阅读历史6.2.2节点。

## 十、版本如何阅读

| 阶段 | 主要工作 |
|---|---|
| 5.9.x | 独立Bootloader、升级/恢复和上位机基础整理 |
| 6.0.0～6.0.2 | 增加低压校准点，处理启动和校准稳定条件 |
| 6.0.3～6.0.4 | 改成直接DAC校准，修复点位保存相关限制 |
| 6.0.5～6.0.7 | 持续PID试验、调参及实时接口 |
| 6.0.8 | R316=4.99kΩ适配，回归DAC映射，修复校准保存与回读 |
| 6.1.0～6.1.5 | SRC供电补丁、基础保护、短路误判修正、阻值和采样试验 |
| 6.2.0 | 固定3.2～32V、8A设定上限；500Hz采样、中文设置、二进制DMA协议 |
| 6.2.1 | 输出理想二极管旁路基准、切页重绘、Vpp统计修复 |
| 6.2.2 | 屏幕休眠、默认25Hz回传、有线同端口恢复 |
| 6.2.3 | 全量程小误差PI |

仓库提供当前完整工程，并精选5.9.3、6.0.4、6.0.8保存修复版、6.1.5、6.2.2作为历史源码节点。历史节点保留当时的控制和硬件前提；某些版本的软件发布检查通过，但对应硬件问题当时仍在排查，不应统一标为“已经实机稳定”。

公开历史包做了目录清理、字体许可补齐及必要的字体替换，并记录原始源包与公开包的SHA256。它们用于学习、比较和复现开发思路；当前板子的默认入口是最新工程及其硬件说明。

## 十一、编译、下载与验证

当前完整工程按顺序提供：01_Bootloader、02_Application、03_Factory、04_Recovery、05_PC_Tool。APP基址为0x08008000，Bootloader位于0x08000000起始的32KiB区域。

已有兼容Bootloader的板子只更新APP，保留W25Q256校准数据。空片可分别编译Bootloader和APP，通过工厂脚本生成合并HEX，再用SWD首次安装。仓库给出地址检查、合并步骤和编译入口，不把APP文件误当成完整空片固件。

上位机基于Python、PySide6和pyserial，可从源码运行或按脚本打包。协议、校准、保护、存储和UI已有离线回归检查。公开字体替换后的构建与检查结果单独记录，避免用旧二进制的结果替代新包验证。

实板验收应记录输入条件、目标、负载、DAC、测量电压、保护现场、实际采样间隔及波形。重点包括3.2/3.3V启动、加载/卸载、降压、短路关断时间、长期热状态，以及切页/休眠/通信同时工作时的调度表现。

## 十二、这次开发留下的经验

1. 固定DAC而实测电压继续漂移时，先沿着参考电压、缓冲输出、FB、转换前后节点查硬件，不能直接认定是软件PID。
2. 改一个反馈电阻，也要同步检查理论映射、持久化曲线和硬件版本标记。
3. 校准保存应有写入确认和读回证据；界面上的成功提示必须对应真实设备状态。
4. 短路判据要匹配实际电流和硬件响应，低电压、小噪声本身不能作为短路证据。
5. 采样频率、屏幕频率、遥测频率和控制带宽是不同概念，需要分别设定和测量。
6. 输出保护、输出隔离和防倒灌是不同功能，旁路硬件以后必须更新产品描述。
7. 保留关键历史版本、硬件前提和未验证项，比只发布一个“最终稳定版”更方便后续开发者复现。

下一步重点是实测PI动态、保护关断延迟和功率热边界，以及在下一版PCB中设计明确的输出隔离/泄放方案。当前开源内容把已完成的软件、实际板上修改和仍需验证的部分一起公开，欢迎基于完整记录继续改进。

## 附：开源内容与致谢

代码、协议、校准说明、硬件补丁、历史节点及外壳文件均见[GitHub仓库](https://github.com/LDO75/XIN_Power)。本项目维护者为LDO75，沿用仓库GPLv3许可；器件库及OFL字体按各自许可保留声明。原作者工程作为来源链接说明，没有将其完整源码包冒充为本项目原创文件重新上传。

感谢原电源项目作者cyxsnbb666，以及提供芯片资料、开源器件库与字体的作者和维护者。

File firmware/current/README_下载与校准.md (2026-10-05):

# XIN Power V6.2.3 — V2补丁硬件，3.2–32V / 最大设定8A

## 下载与使用

- `XIN_Power_V6.2.3_APP_USB_BT.hex`：APP，地址0x08008000，不含Bootloader。
- `XIN_Power_Studio_V6.2.3.exe`：新版Windows上位机，含25Hz默认回传和有线同端口恢复。
- `XIN_Power_V6.2.3_Source.zip`：Keil APP工程、Qt上位机、协议和回归检查源码。
- `realtime_settings.json`：放在EXE旁边开启本机实时读取/控制接口；不会自动连接COM14。

沿用已经安装的Bootloader。升级应用时保留W25Q256与原Bootloader，不做全片擦除或CAL RESET。新版上位机能读取旧协议4固件并上传新版APP；新版APP的常规通信采用协议5。普通旧串口助手发送INFO后也可使用兼容文本通道，文本回传最高10Hz。

本次添加全量程小误差PI微调，保留屏幕休眠、25Hz回传与有线恢复，未连接电源串口、烧录或带载实测。首次烧录后请先核对固件6.2.3、硬件V2、采样周期2ms和校准表。

## 硬件基准

| 项目 | 本版基准 |
|---|---|
| R274 | 100kΩ |
| R314 + R315 | 7.5kΩ + 120Ω = 7.62kΩ |
| R316 + R317 | 4.99kΩ + 120Ω = 5.11kΩ |
| R292泄放 | 用户确认实装1.8kΩ |
| 输出理想二极管 | 用户确认MOS D/S已短接旁路，后续版本采用此基准；输出无此级防倒灌功能 |
| DAC参考 | 3.000V，MCP4725，4096码比例 |
| 调压方式 | 正常输出先用校准点线性映射，在实测误差±100mV内PI微调；手动校准固定DAC，不做恒流 |

8A是电流设定上限，不表示32V可以连续输出8A。保留输入4.8A过流阈值；28V输入对应约134.4W输入功率，输出还受损耗和硬件能力约束。

## 固件界面与任务频率

- INA226每2ms轮询，目标500Hz，保持0x4097连续转换、332µs母线/分流转换、平均1次。芯片完成标志CVRF确认后才算新样本。
- 输出INA电流优先读取并解算，马上检查过流，然后读取电压与输入通道。单路电压读取失败或另一颗INA失败，都不会屏蔽已读到的有效过流电流。
- 屏幕20ms更新，目标50Hz，只传变化的数字区域；SET/OCP栏未变化时不重复发送。LCD分段发送期间继续让出前台给采样和保护；没有在中断里进行阻塞I²C。
- 串口常规遥测40ms一次，目标25Hz，双UART发送使用DMA，收命令仍使用中断字节环形队列。
- 主界面中间栏左侧“波动 Vpp”、单位mV，右侧功率。设备波形页面已删除。主界面右滑打开左侧设置，设置页左滑返回。
- 设置页中文黑体，含亮度、蜂鸣器、方向、电流零点校准、屏幕休眠、版本。主界面其余布局保持原样。

“波动 Vpp”取最近1秒有效的原始校准后输出电压最大值减最小值，最多500个采样，未经过显示低通；过期/失联时显示无效。它是低频采样波动，不是开关频率纹波测量。零点电流与R292泄放电流修正保留，过流判断使用扣除泄放前的电流。

这些是调度目标，实际速度由总线、触摸、Flash等操作决定。上位机日志/CSV同时记录实测采样Hz与最大样本间隔，不以25Hz遥测声称500Hz采样始终达标。INA测量不是硬件比较器，不能承诺2ms内必然完成短路关断。[INA226时序资料](https://www.ti.com/lit/ds/symlink/ina226.pdf)。

## 基本保护完整列表

| 保护 | 判定 | 动作 |
|---|---|---|
| 输出过流/短路大电流 | 有效电流大于用户设定（0.1–8A）；绝对备用上限8.5A；校准前/后电流取较大值 | 首个有效越限读数关断并锁存，IOUT_OC |
| 输入过流 | 大于4.8A | 首个有效越限读数关断并锁存，IIN_OC |
| 输入欠压 | 小于4.0V持续200ms | 关断并锁存，VIN_UV |
| 输出绝对过压 | 大于33.0V | 有效测量判定后关断并锁存，VOUT_OV |
| 输出相对过压 | 大于参考电压 + max(300mV,参考的10%)持续100ms | 关断并锁存，VOUT_OV |
| 过温 | 有效温度大于等于80℃ | 关断并锁存，OTP |
| INA持续失联/数据冻结 | 输出开启时完整新样本中断500ms（默认采样周期下） | 关断并锁存，MON_OFFLINE |

清除故障后仍保持输出关闭，需要手动再次开启。没有低电压SHORT判据，没有50mA门槛，没有额外启动短路延时，没有功率限制、恒流控制或自动恢复输出。温度传感器无效时沿用原逻辑，不新增NTC失联故障。

手动DAC校准允许输出电压与点位目标不同，因此此期间暂停相对过压；绝对33V过压、过流、输入欠压、过温、INA失联仍保留。DAC微调仍只有12位码范围与写入成功检查，不要求测量先贴近目标才能保存。

降压时相对过压参考按R292×输出电容量的RC上界下降，不能无限停留在旧目标。估计输出电容400µF（板内名义约333µF加容差），R292=1.8kΩ，τ=720ms；更快的真实下降也可降低参考。外接很大电容会改变放电时间，不能把此估算视为所有负载的实测保证。

## 校准表

新表schema5、16点，ID按电压升序：

`3.2、3.3、3.5、3.8、4.0、4.2、5、7.2、8.4、9、12、18、20、24、28、32V`。

选点 → 微调DAC → 输入万用表实测 → 采集并保存。每个点独立保存、保存后关闭输出，立即用于映射，无需等16点全部完成。上位机必须收到确认并读回相同实测值和DAC才显示保存成功。没有实测点的区间先使用现有邻点/理论斜率，不代表这些区间已经精密校准。

已有schema3/4、硬件标记0x4991的表按“名义电压”迁移，绝不沿用旧ID含义：保留3.3、4、5、7.2、8.4、9、12、18、20、24、28、32V共12个匹配点；新增3.2、3.5、3.8、4.2V等待实测。旧2、3、3.6、3.9、4.5V点不再作为新表点位。启动迁移只读原记录；实际保存时才写新schema5双备份，保留测量校准系数。其他阻值配置的旧DAC标记不能混用。

旧设定低于3.2V时钳位到3.2V，保留电流设定，输出启动保持关闭。

## 上位机

左下角集中放置“有线USB/无线蓝牙”选择、端口、扫描、连接/断开、连接状态与固件版本。扫描只枚举系统端口，不逐个打开或自动换到蓝牙；连接时只验证用户选中的端口。无线显示Windows已经配对的蓝牙串口，未配对设备需先在系统配对。

后台接收/解包，界面每20ms批量更新；日志用中文解算摘要，显示最近1000条，状态摘要5条/秒，后台完整记录收到的全部数据，默认25Hz。记录使用后台缓冲写盘；CSV保留真实电压、DAC、CE、波动、采样Hz等。清空显示不会删除后台记录。实际日志位于系统临时目录XINPowerStudio，导出使用完整已落盘记录。

正常模式仅一条命令等待确认；超时重试使用同一序号和原字节。固件缓存最近4条请求的完整响应，重复STEP/CAPTURE不再次执行；序号相同但参数不同拒绝执行。OUT OFF/停止校准走优先发送队列，不能被一串查询拖在后面。

## 已验证与待实测

已通过真实固件源代码的C回归：16点保存/映射、旧表迁移、Flash失败回滚、单路过流、保护阈值与锁存、降压参考衰减、500Hz/CVRF、Vpp过期、DMA队列、CRC、重复命令、UART错误恢复、设置保存、LCD局部像素/中文显示。上位机19项当前版本测试通过，含C端数据包到Python解包、完整二进制升级状态机、端口选择、Qt页面加载与最小窗口。最终Keil零错误零警告并通过RAM/栈检查，EXE已打包。

仍需由用户实机验证：3.2/3.3V启动与负载变化，降压过渡，过流阈值/关断延迟，切页/触摸时实际采样与回传频率。关闭后约0.2V波动保持实测显示；关闭输出时本版没有周期性DAC/CE脉冲，但不能据软件检查宣称硬件残压已经消失。

## 6.2.1显示补丁

- 完整切页与显示方向重绘：先全屏清黑，再填充新页面；返回主界面强制完整重画顶栏，不依赖VIN/TEMP变化。普通50Hz刷新仍为局部更新。
- Logo绘制前也清黑。Vpp/功率局部刷新使用与完整面板相同的背景合成，保留圆角边框。
- 二进制INFO、文字INFO和设置页的版本号统一使用共享定义，设备均报告6.2.3。
- 以实际输出使能和已应用的映射DAC基准检测调压，手动校准使用实际DAC，包括上位机、屏幕与校准微调；暂停Vpp取样并清空旧窗口，保留最后一个有效Vpp。首次尚无有效值时显示“-- mV”。
- 变化后至少等待200ms，再要求连续400ms电压采样跨度不超过20mV；稳定后重新收集1秒数据，才更新Vpp。升降压期间不会把旧、新电压混入同一个窗口。持续调压会重新开始等待。
- 稳定准入只在输出/DAC变化或采样恢复后运行；恢复统计后，真实波动即使大于20mV也照常显示。采样失效或间隔超过20ms时Vpp失效，恢复后重新确认稳定和收集窗口。
- 以上仅改变Vpp统计，500Hz电流读取和关断保护照常运行，DAC校准映射、故障阈值、协议5和Flash校准地址保持兼容。短接理想二极管不会被软件模拟成输出隔离开关。

每次切页增加一次全屏SPI传输，可能短暂看到黑色过渡。清黑能处理遗漏像素；若实机清黑后仍存在残影，需再区分屏幕图像残留、驱动参数和光学反光，离线栅格测试不能证明液晶物理残留已经消失。

## 6.2.2屏幕休眠与通信补丁

- 默认休眠1分钟。在设置页向上滚动找到“屏幕休眠”，点卡片依次选择：关闭、30秒、1分钟、2分钟、5分钟、10分钟。
- 无触摸达到时限后先关闭背光并清屏为黑；供电输出、DAC、采样、保护、串口和校准任务继续。任何有效触摸唤醒当前页面，重绘完成再恢复此前亮度。
- 唤醒的一整次按下/移动/抬起不执行按钮、滑动或调压操作；下一次触摸才操作界面。触摸失联时不主动休眠，以免无法唤醒。
- 时限修改即时生效。设置schema3使用原记录的保留字节，兼容schema1/2并默认1分钟；记录布局和电压校准Flash地址不变。设置写盘仍等输出关闭后进行，不为了保存时限主动关闭电源。
- 两个串口分别默认40ms/25Hz，INFO报告实际配置周期；RATE接受20–5000ms，改变命令所在通道。上位机可选25/10/5/50Hz。文本兼容通道最高10Hz。500Hz采样、50Hz屏幕刷新不变。
- 新上位机连接6.2.2及以上时发送LOG RATE 40和STATUS，读取设备真实状态。有线系统读写异常最多恢复同一端口5次，间隔1.8秒；手动断开、改选端口或连接方式可取消。恢复不重发旧连接的开关输出、调压、采集保存等操作。
- 命令缺少最终确认时保留串口接收，提示操作结果未知。正常的同序号重试仍保留，最终超时之后不继续执行重试。
- 日志摘要每秒最多5条，只是显示节流；完整数据照常记录。实际25Hz需结合上位机回传速率和完整记录确认，不能用可见日志行数判断。

有线断链记录来自Windows串口API的“拒绝访问”，并非CRC错误或固件协议超时；降低回传和自动恢复不能证明设备/驱动故障根因已经消除，详见《有线断链分析.md》。未打开实机串口或执行烧录。

## 6.2.3全量程小误差PI

3.2–32V正常输出都可微调。实测误差定义为设定mV减校准后未经过显示滤波的输出mV；进入-100至+100mV（含边界）后计算PI。超过100mV时停止积分/调码，保持当时已应用DAC，不跳回映射值。重新进入范围时无突变地重建积分起点。

这是误差准入范围，不是总补偿幅度上限，不保证负载突变的瞬态电压永远在±0.1V。若压降超过100mV且硬件不能自行回到范围，本版按用户要求不会主动追赶。

Kp=0.20、Ki=2.00/s、Kd=0；这是待带载验证的试验参数。每个新INA样本最多计算一次，实际dt积分；8mV死区、0.65 DAC码决策滞回、每次最多1码且写入间隔至少10ms，DAC范围0–4095，饱和时回算积分。没有要求每2ms都写DAC。正常闭环微调不会冻结Vpp，实际波动照常统计。

更改电压设定、关闭输出、故障关断、进入手动校准时重置PI；手动校准不自动调DAC、不改已保存校准点。采样无效/间隔超过20ms暂停微调，原500ms监测失联保护仍保持。过流与其他原保护优先处理，阈值不变。

上位机诊断与中文日志显示PI微调/暂停和误差mV，CSV最后追加两列。PI基础参数集中在power_config.h，本次没有复用旧6.0.6的连续全范围PID调参接口。

编译、模型及边界验证见QA_6.2.3.md和PI控制说明.md；没有实机连接或负载调参。

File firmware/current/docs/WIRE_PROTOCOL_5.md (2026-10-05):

# XIN Power V6.2.3 通信协议5

实现：固件wire_protocol.h/.c与debug_console.c；上位机wire_protocol.py。115200，8N1。实际二进制字节，不发送ASCII形式的HEX字符串。多字节整数小端、有符号整数补码、字段连续无结构体填充。

## 帧格式

| 帧偏移 | 长度 | 字段 |
|---|---|---|
| 0 | 2 | A5 5A同步头 |
| 2 | 1 | 版本05 |
| 3 | 1 | 类型 |
| 4 | 2 | payload长度u16，最多448 |
| 6 | 2 | 序号u16 |
| 8 | payload长度 | payload |
| 8+payload长度 | 2 | CRC16 |

CRC16-CCITT：poly=0x1021，init=0xFFFF，无反射、无最终异或。覆盖偏移2开始的版本/类型/长度/序号/payload，不含同步头和CRC。Python为binascii.crc_hqx(body,0xffff)。总长度=payload长度+10。CRC/版本/长度错误重新找帧头；不完整帧间隔超过200ms清除。

| 类型 | 内容 |
|---|---|
| 1 | 命令：opcode u8 + 参数 |
| 2 / 3 | ACK / ERR：opcode u8 + ASCII说明/原因，无结束零 |
| 4 | INFO，29字节 |
| 5 | 遥测，77字节 |
| 6 | 故障现场，41字节 |
| 7 | 曲线概况，7字节 |
| 8 | 单点，9字节 |
| 9 | 校准状态，10字节 |
| 10 | 测量校准，33字节 |
| 11 | 少量诊断/帮助/升级状态UTF-8文本，仍封装在二进制帧内 |

77字节遥测不用sprintf，整帧87字节，默认25Hz=2175字节/秒，占115200 8N1约19%；可选50Hz约38%。双UART DMA，命令/故障预留空间；遥测拥塞丢弃整帧，下周期发最新状态，不阻塞采样。

## 命令payload

以下参数不含opcode。u/i为无符号/有符号位宽。

| opcode | 操作 | 参数 | 主要回复 |
|---|---|---|---|
| 1 | HELLO/INFO | nonce u32 | INFO |
| 2 | STATUS | 无 | 遥测；故障时附现场 |
| 3 | SET V | mV u16，3200–32000 | ACK/ERR |
| 4 | SET I | mA u16，100–8000 | ACK/ERR |
| 5 | OUT | u8，0关/1开 | ACK/ERR |
| 6 | CLEAR | 无 | ACK/ERR |
| 7 / 8 | CAL GET / RAW | 无 | 测量校准 |
| 9 / 10 | CAL SET V / I | gain i32，offset i32 | ACK/ERR |
| 11 / 12 | CAL SAVE / RESET | 无 | ACK/ERR |
| 13 | CURVE GET | 无 | 曲线概况 |
| 14 | POINT GET | id u16，0–15 | 单点 |
| 15 | POINT START | id u16，0–15 | ACK/ERR |
| 16 | POINT STEP | delta i16，只接受−5/−1/1/5 | ACK/ERR |
| 17 | POINT CAPTURE | 实测mV u16，1–65535 | ACK/ERR |
| 18 / 19 | POINT STOP / STATE | 无 | ACK / 校准状态 |
| 20 | LOG | u8，0关/1开 | ACK/ERR |
| 21 | RATE | u16，20–5000ms，默认40ms，分别设置命令所在通道 | ACK/ERR |
| 22 / 23 | DIAG / HELP | 无 | 诊断文本 |
| 24 | PING | 无 | ACK |
| 30 | FW STATUS | 无 | 升级状态文本 |
| 31 | FW BEGIN | size u32，CRC32 u32，versionCode u32 | ACK/ERR |
| 32 | FW DATA | offset u32 + 1–192个固件字节 | ACK/ERR |
| 33–35 | FW END / APPLY / ABORT | 无 | ACK/ERR |

versionCode例：6.2.0=60200。36保留，APP当前没有REBOOT处理。测量gain为ppm（1000000表示1倍），offset V为mV/I为µA，沿用原系数接口。

请求序号递增，回复沿用。异步遥测和故障使用独立事件序号，可能与请求序号数值相同，不能只按序号匹配ACK。普通请求仅一条在途，1.2s未确认最多重发2次，字节/序号完全相同；FW BEGIN/END首次等待90/45s。OUT OFF/STOP可先于等待中的查询发送。

每通道固件缓存最近4条完整请求/回复：相同序号+payload只重放，不重复STEP/CAPTURE；同序号不同payload拒绝。HELLO随机nonce变化清缓存。上位机按序号/类型/内容去重回复；遥测与故障不按请求去重。超时后须查询确认，不能当成保存成功。

## INFO（29字节）

依次：major/minor/patch/hardwareVersion各u8；vmin/vmax/imin/imax/sample_ms/screen_ms/telemetry_ms/rinj/hardware_tag各u16；points u8；flags u8；baud u32；otaCode u8。

电压mV，电流mA；V2，rinj=5110Ω，tag=0x4991，points=16。flags bit0=Flash可用、bit1=Bootloader可用。otaCode：0无、1暂存、2复制、3试运行、4确认、5回退、6取消、7校验、8设置保存忙。

## 遥测（77字节）

以下偏移相对于payload；无效时仍传最近记录的数值，应检查flags；关闭输出不伪造电压0。

| payload偏移 | 字段 | 类型 | 含义 |
|---|---|---|---|
| 0 | t | u32 | 设备发送时刻ms |
| 4 | seq | u32 | 完整采样序号 |
| 8 | samplet | u32 | 最近完整新样本时刻ms |
| 12 | vin | u16 | 输入mV |
| 14 | iin | i32 | 输入µA |
| 18 | pin | u32 | 输入mW |
| 22 | vout | u16 | 输出校准后mV |
| 24 | iout | i32 | 输出校准后并扣除泄放µA |
| 28 | pout | u32 | 输出mW |
| 32 | temp | i16 | 0.1℃ |
| 34 | setv | u16 | 目标mV |
| 36 | seti | u16 | 用户阈值mA |
| 38 | ilim | u16 | 实际保护阈值mA |
| 40 | dac | u16 | 12位DAC码 |
| 42 | vraw | u16 | 未校准输出mV |
| 44 | iraw | i32 | 未校准输出µA |
| 48 | vfast | u16 | 校准后未显示滤波mV |
| 50 | flags | u16 | 状态位 |
| 52 | fault_code | u8 | 故障码 |
| 53 | vpp | u16 | 最近1秒低频波动mV |
| 55 | hz | u16 | 实际采样Hz |
| 57 | maxgap | u16 | 统计期最大样本间隔ms |
| 59 | dw | u32 | DAC写入次数 |
| 63 | dwt | u32 | 最近写入时刻ms |
| 67 | rxdrop | u16 | 本通道RX溢出计数低16位 |
| 69 | txdrop | u16 | 本通道TX丢包计数低16位 |
| 71 | in_errors | u16 | 输入INA错误计数低16位 |
| 73 | out_errors | u16 | 输出INA错误计数低16位 |
| 75 | ntcraw | u16 | NTC ADC码 |

flags bit0=req请求开启、1=out实际开启、2=valid完整测量有效、3=CE脚高、4=输入INA在线、5=输出INA在线、6=Vpp有效、7=温度有效、8=PI微调准入（校准/关闭/误差超范围时0）、9=具备本版小误差PI，其余保留0。CE为关断高有效。hz/maxgap是采样统计，不是遥测频率。Vpp取最近1秒未显示滤波的校准后输出电压max−min，是低频波动。

## 故障（41字节）

依次：t u32；faultCode u8；phase u8；set/dac/vout/vuncal/vin各u16；iin/iout_uncal各i32；pout u32；temp i16；flags u8；age/seq各u32；ilim u16。

t为触发时刻ms；电压mV、电流µA、功率mW、温度0.1℃、ilim mA。flags bit0=完整测量有效、1=输入在线、2=输出在线。age为最近完整双路样本年龄，不伪装为此次电流时间；即时过流可以先于母线电压读取触发，所以故障电压可能来自上一完整样本。

故障码：0 NONE、1 MON_OFFLINE、2 VIN_UV、4 VOUT_OV、5 IIN_OC、6 IOUT_OC、10 OTP。短路大电流走过流路径，无低压SHORT码。先关CE后入队故障，LOG OFF仍发故障，锁存后STATUS也读回现场。

## 校准回复

- 概况7字节：schema u8=5，mask u32，saved u8，total u8=16。
- 单点9字节：id u8，target u16，valid u8，actual u16，dac u16，saved u8。
- 状态10字节：active u8，id u8，target/dac/vout各u16，ready u8，faultCode u8。
- 测量校准33字节：flags u8；vgain/voff/igain/ioff各i32；v1/c1/v2/c2/vraw各u16；iraw i32；dac u16。flags bit0=总有效、1=电压有效、2=电流有效、3=两点DAC有效、4=已保存。

电压mV，DAC0–4095，mask bit id=实测有效。CAPTURE成功ACK后读回同一actual与dac，才标记保存成功。单点保存立即应用。

## 兼容与检查

空闲应用通道不主动发ASCII。上位机先二进制HELLO，无回复才换行清旧APP命令缓冲并发文本INFO，不改变输出。协议4/旧Bootloader保留。显式文本INFO进入兼容模式，遥测最多10Hz。

tests/test_console_620.c通过真实固件命令处理生成tests/wire_vectors_620.bin；PC tests/test_620.py解析该文件校验双方布局，覆盖CRC、重试去重、OTA和新旧校准表。旧上位机未适配新点位ID，建议配套使用6.2.3。

6.2.3 INFO的控制类型由版本识别为DAC_PI；误差pe由setv−vfast在上位机计算。帧长度/偏移不变，旧软件忽略原保留高位仍可解包。

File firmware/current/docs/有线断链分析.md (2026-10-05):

# 6.2.2有线断链分析

## 日志证据

用户提供19:26起日志，在19:28:21报告ClearCommError failed / PermissionError(13,拒绝访问,Windows错误5)，19:28:42报告GetOverlappedResult failed / 同类错误。19:28:27与19:28:57再次打开COM9均收到6.2.1 INFO。

这些错误来自Windows串口API调用失败；pySerial以异常形式报告。不是固件返回的FAULT、CRC错误或ACK超时。日志不足以判断设备是否复位、USB瞬断、串口驱动异常或电气干扰，也不能凭输出OFF推定MCU复位。
依据：[pySerial Windows实现](https://github.com/pyserial/pyserial/blob/master/serial/serialwin32.py)、[Microsoft ClearCommError](https://learn.microsoft.com/en-us/windows/win32/api/winbase/nf-winbase-clearcommerror)。

## 本版修正

二进制调度原来写死20ms，RATE不生效。本版按各通道周期调度，默认40ms；87字节一帧，25Hz=2175字节/秒，占115200 8N1约19%，50Hz约38%。原50Hz理论上也未超过线路带宽，不能把Windows“拒绝访问”简单归因为回传太快。

上位机保持后台接收/DMA固件，系统读写错误保留完整原因并尝试恢复原有线端口5次，1.8秒间隔。重新握手配置40ms并读取STATUS，不自动恢复输出，不重发旧的调压或校准保存。扫描不会替换恢复端口，手动操作可取消。蓝牙不自动切换进入此有线恢复流程。

普通命令最终确认超时独立处理，继续接收并报告操作结果未知。当前命令同序号重试仍用于应对丢包，最终超时之后结束该命令；应通过读取状态确认。

## 实测判断

日志的中文状态摘要限5次/秒，完整数据在后台记录；不能根据摘要条数认定回传5Hz。实测查看回传速率和CSV/JSONL中的全部遥测。
若新版仍触发Windows错误，请保留断链前后日志；结合Windows设备是否消失重现、USB驱动/线缆、供电与高电流切换条件进一步定位。本版改善恢复和诊断，没有实机证据证明根因消失。

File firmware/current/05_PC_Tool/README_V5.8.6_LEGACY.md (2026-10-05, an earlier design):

# XIN Power 上位机 V5.8.6

同一个上位机支持两种连接，并使用同一套命令和日志协议：

- USB 转串口：固件 USART1，PA9/PA10，115200 8N1。
- VG6328A 无线串口：固件 USART2，PA2/PA3，115200 8N1。

## VG6328A 在 Windows 中叫什么

VG6328A 是模块型号，不是出厂广播名。原厂默认名称为：

| Windows/手机看到的名称 | 类型 | 本工具是否使用 |
|---|---|---|
| `XLBT` | 经典蓝牙 SPP | 是，配对后生成 COM 口 |
| `XLBLE` | BLE GATT | 否，不会直接生成传统串口 COM |

Windows 应配对 `XLBT`。配对完成后，回到主界面点击“扫描”，等待程序通过 `PING`/`INFO` 识别设备；在端口列表中确认目标 COM 口，然后点击“连接”。扫描、选择和连接都在主界面完成，不必进入校准页。已知 COM 口时也可直接在主界面选择并连接。

蓝牙 SPP 可能在扫描探测后需要短暂释放端口；若首次连接失败，请等一两秒后对同一端口重试，并检查 Windows 中 `XLBT` 已配对且对应的传出 COM 口可用。不要选择仅提供 BLE 的 `XLBLE`。

界面内的“蓝牙连接向导”也包含同样的分步说明。

> 原厂资料给出的默认 UART 是 115200 8N1，默认同时开启 BLE 和 SPP。若要改名，模块需先进入 AT 模式；SPP 名称使用 `AT+SPNA...`，BLE 名称使用 `AT+LENA...`，设置后复位生效。普通设备控制命令不要直接当作模块 AT 通道使用。

## 直接运行

Windows 安装 Python 3.11 或更新版本后，双击 `run_windows.bat`。脚本只在本目录建立虚拟环境并安装依赖。

## 打包成单文件 EXE

双击 `build_windows.bat`，完成后得到：

`dist\XIN_Power_Console_V5.8.6.exe`

该 EXE 不要求目标电脑安装 Python。源码交付包不携带庞大的虚拟环境或预编译EXE；需要发布时，在Windows上双击`build_windows.bat`即可重现打包。

## 新版界面

- 深色仪器面板：输出电压、电流为主读数，输入、电功率、温度和设定值为次级读数。
- 主界面提供扫描、端口选择、连接和断开；协议探测通过 `PING`/`INFO` 确认真正的 XIN Power。
- 统一调试终端：TX、RX、ACK、错误和遥测帧采用固定颜色与毫秒时间戳。
- 链路状态：显示 USB/蓝牙类型、固件版本、协议版本和遥测新鲜度。
- 保留趋势图、原始命令、完整日志导出和 CSV 遥测记录；电压以三位小数显示。
- 同时显示用户设定限流和固件综合100W/输入能力后的有效限流。
- 设置页保留外部标准仪表参与的高精度电压两点校准，同时提供输出电流和 DAC 校准向导。

## 自动校准

请先确认电源板与固件匹配、参考源配置正确。连接后打开“设置 / 校准”，准备可信的万用表和电子负载，按向导依次完成：

1. 输出关闭时自动采集电流零点。
2. 设备自动设置 5V，输入万用表实际电压，可精确到 0.001V。
3. 设备自动设置 20V，输入万用表实际电压，可精确到 0.001V。
4. 设备回到 5V/2A，接入 0.5～1.5A 负载并输入实际电流。
5. 上位机自动计算电压/电流增益与零点、DAC 两点映射，关闭输出后写入 W25Q256 双备份校准区。

没有外部标准仪表时无法得到真实校准值；0.001V 是输入与显示分辨率，不代表整机已达到 1mV 绝对精度。向导自动化的是切换、采样、计算和保存过程。

## 固件命令

每条命令以回车或换行结束，不区分大小写：

| 命令 | 作用 |
|---|---|
| `PING` | 链路测试 |
| `INFO` | 固件与协议版本 |
| `STATUS` | 立即返回一帧遥测 |
| `SET V 5000` | 输出设定为 5000mV |
| `SET I 1000` | 软件限流设定为 1000mA，允许100～8000mA |
| `OUT ON` / `OUT OFF` | 开启/关闭输出 |
| `LOG ON` / `LOG OFF` | 开启/关闭当前通道日志和遥测 |
| `LOG RATE 500` | 遥测间隔，允许 100～5000ms |
| `CLEAR` | 请求关闭输出，使现有保护状态安全复位 |
| `CAL GET` / `CAL RAW` | 读取校准参数与未校准原始值 |
| `CAL SET V gain offset` | 设置输出电压 ppm 增益与 mV 零点 |
| `CAL SET I gain offset` | 设置输出电流 ppm 增益与 µA 零点 |
| `CAL SET DAC v1 c1 v2 c2` | 设置两个实际电压/DAC码点 |
| `CAL SAVE` | 输出关闭时保存校准参数到 Flash |
| `CAL RESET` | 仅将当前运行参数恢复默认值（未保存） |
| `HELP` | 输出命令摘要 |

结构化数据以 `@` 开头；原有人工诊断日志仍保持 `[INA226]`、`[POWER]`、`[NTC]` 等格式。兼容协议版本 3 的 `@TEL` / `@CAL` 字段，包括 `ilim`、`vvalid`、`ivalid` 和 `schema`。VG6328A 单个串口包不超过 255 字节，固件遥测帧已按该限制设计。

## 手动验收（不需要长时间测试）

1. 保持输出关闭，先用 USB：在主界面点击“扫描”，选择标记为 XIN Power 的 COM 口，再点击“连接”；确认状态变为已连接并出现实时读数。断开后重复一次。
2. 已配对 `XLBT` 时，用其 SPP COM 口重复“扫描 → 选择 → 连接”；无需打开校准页。若扫描识别到多个设备，逐个选择目标端口核对。
3. 在输出关闭时发送 `INFO`、`STATUS`，确认终端收到响应；随后用低风险设定值和合适负载短暂验证输出开/关及电压、电流读数。
4. 进入“设置 / 校准”，确认 5V 与 20V 电压步骤仍可录入三位小数。真正写入校准值前，须接好标准仪表并按提示完成全部步骤；仅检查界面时不要启动校准。
5. 如需持续负载试验，可开启 CSV 记录并导出日志；长时间稳定性测试请由用户在安全监护下自行进行。

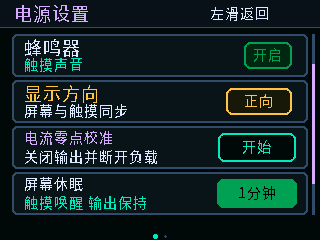
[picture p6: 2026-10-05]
docs/images/device_settings_scroll_open.png

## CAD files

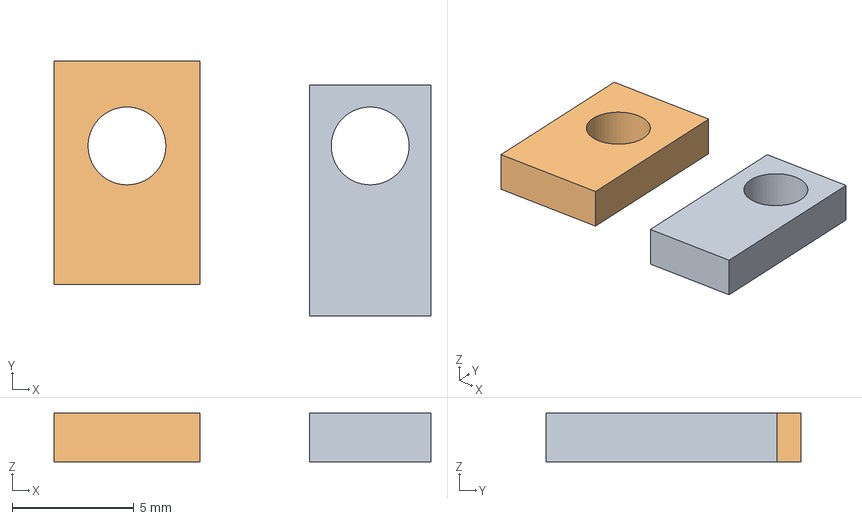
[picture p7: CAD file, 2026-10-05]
hardware/enclosure/XIN_Power外壳压片.step
15.5 x 10.5 x 2.00 mm

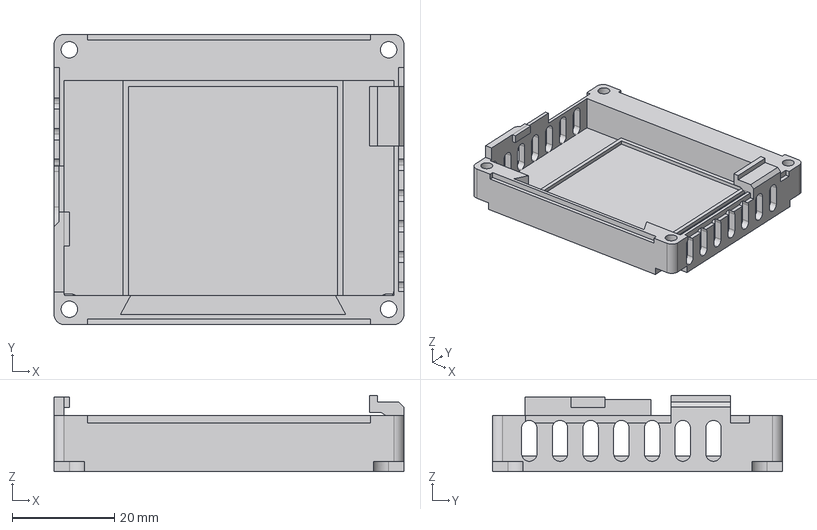
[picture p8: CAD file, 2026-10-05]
hardware/enclosure/XIN_Power外壳下.step
68.4 x 56.7 x 14.9 mm

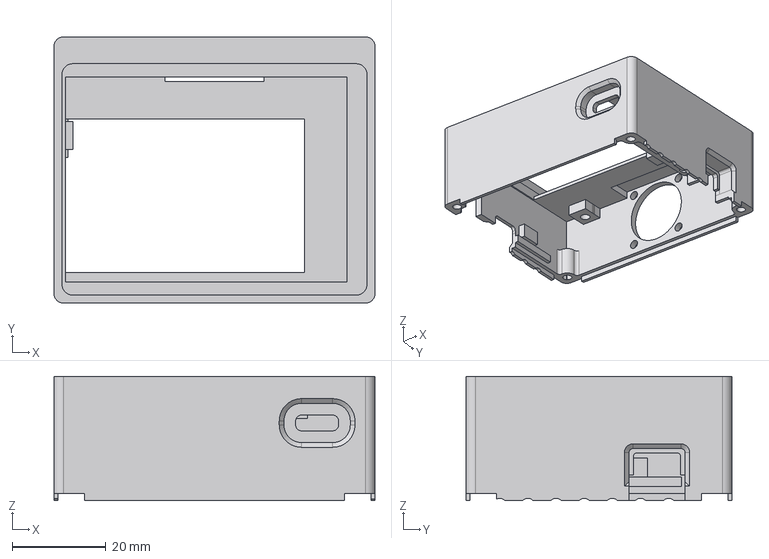
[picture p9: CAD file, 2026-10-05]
hardware/enclosure/XIN_Power外壳上.step
68.4 x 56.7 x 26.5 mm

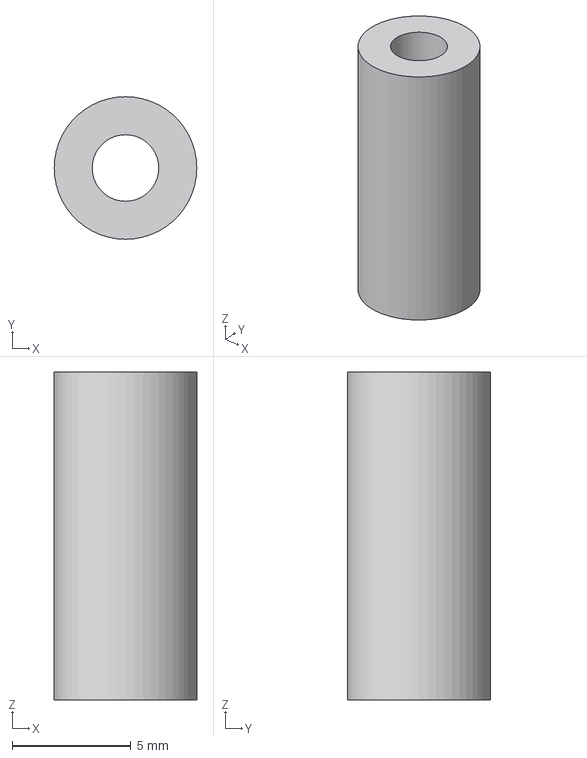
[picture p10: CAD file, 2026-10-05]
hardware/enclosure/XIN_Power外壳支柱.step
6.00 x 6.00 x 13.8 mm

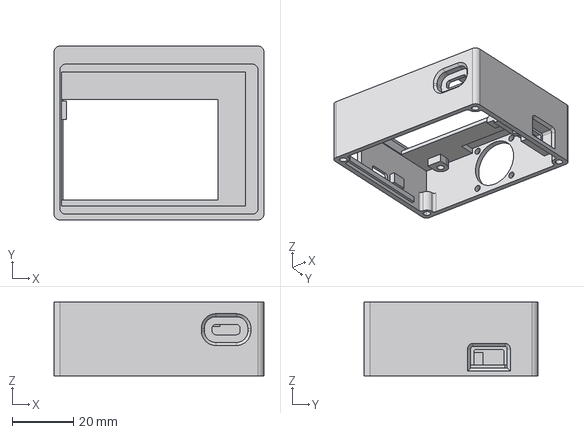
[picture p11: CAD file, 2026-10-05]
hardware/enclosure/XIN_Power外壳.step
68.4 x 56.7 x 24.0 mm

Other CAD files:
hardware/enclosure/XIN_Power外壳下.3mf

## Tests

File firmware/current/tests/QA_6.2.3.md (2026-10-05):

# V6.2.3验证范围

真实生产C回归通过：原16点校准/迁移/Flash、保护/锁存、500Hz/Vpp、DMA协议、UI清屏/休眠/设置保存；新增全量程±100mV含边界准入、超范围保持码、重复样本不积分、手动校准固定码、新设定重置/写失败后重试、饱和后反向恢复、采样失效/长间隔/计时回绕、限流优先，以及正常PI期间Vpp事件标识保持。

216组假设一阶功率响应模型（时常5–200ms、延迟0–20ms、增益0.5–1.5倍、±80mV加载/卸载、±2mV噪声）通过；模型配置及结果见model_summary_623.json，不是实际SC8701/MOS的SPICE模型或真实波形。

当前上位机test_620/test_622/test_623共19项通过，含真实固件字节包PI状态、77字节兼容、老数据包、中文日志、诊断及29列CSV。保留有线原端口恢复测试。源码ZIP只打包当前测试入口，历史旧PID/12点/17点/2V测试不作为本版验收。

Keil0错误0警告。RAM55376/65536，栈8192、静态最大3620，留2048后余量2524字节。静态预算不等于实机栈高水位。PC打包后离屏启动/截图/退出，固件版本/APP向量/ZIP源文件与CRC均检查。

未连接实机、烧录、校准或带载整定。实际负载过冲、恢复时间、量化波动、PI服务时采样抖动和实际回传25Hz需要用户测量。PI只在±100mV内工作；不承诺更大压降自恢复。保护阈值、睡眠和25Hz通信沿用6.2.2。

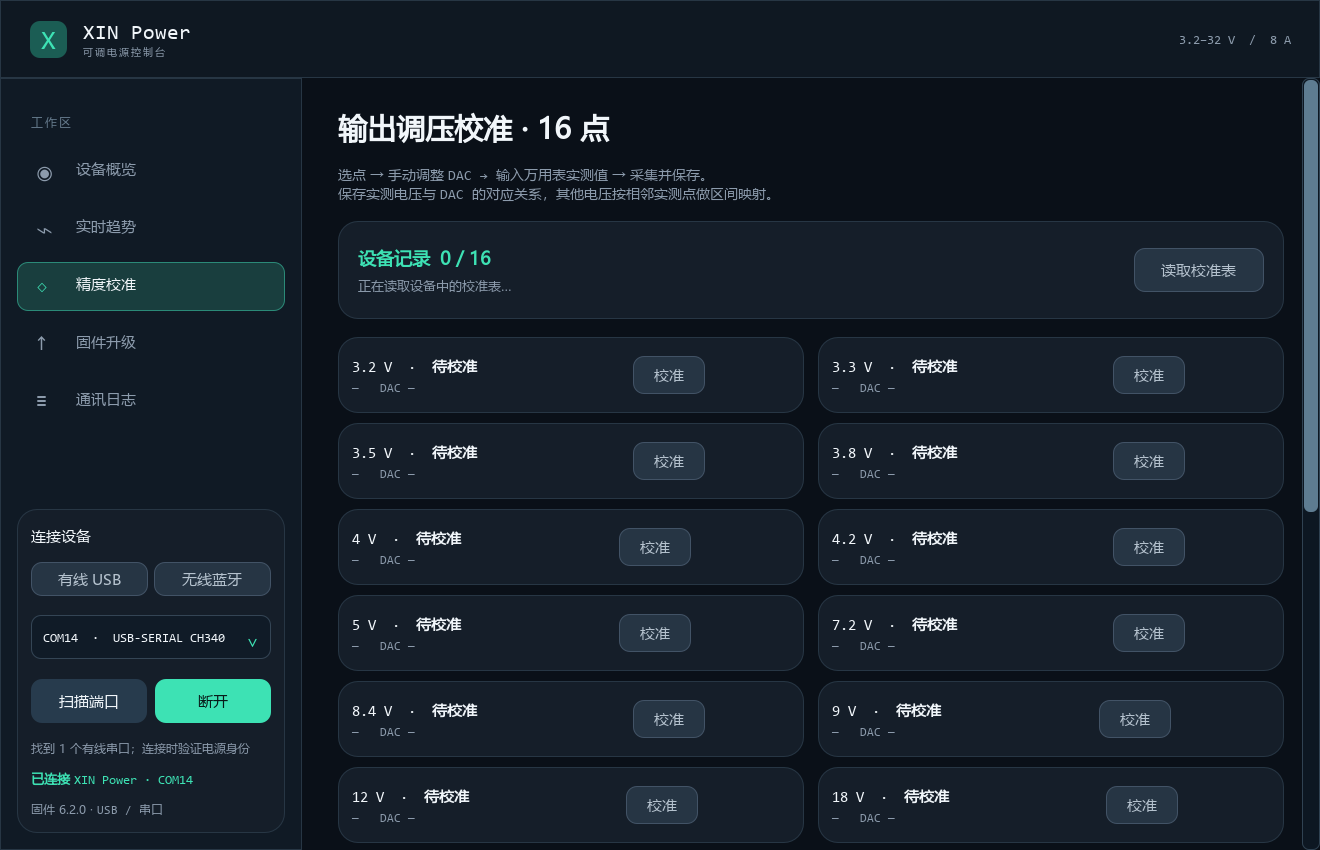
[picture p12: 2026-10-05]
firmware/current/05_PC_Tool/tests/page_620_2.png

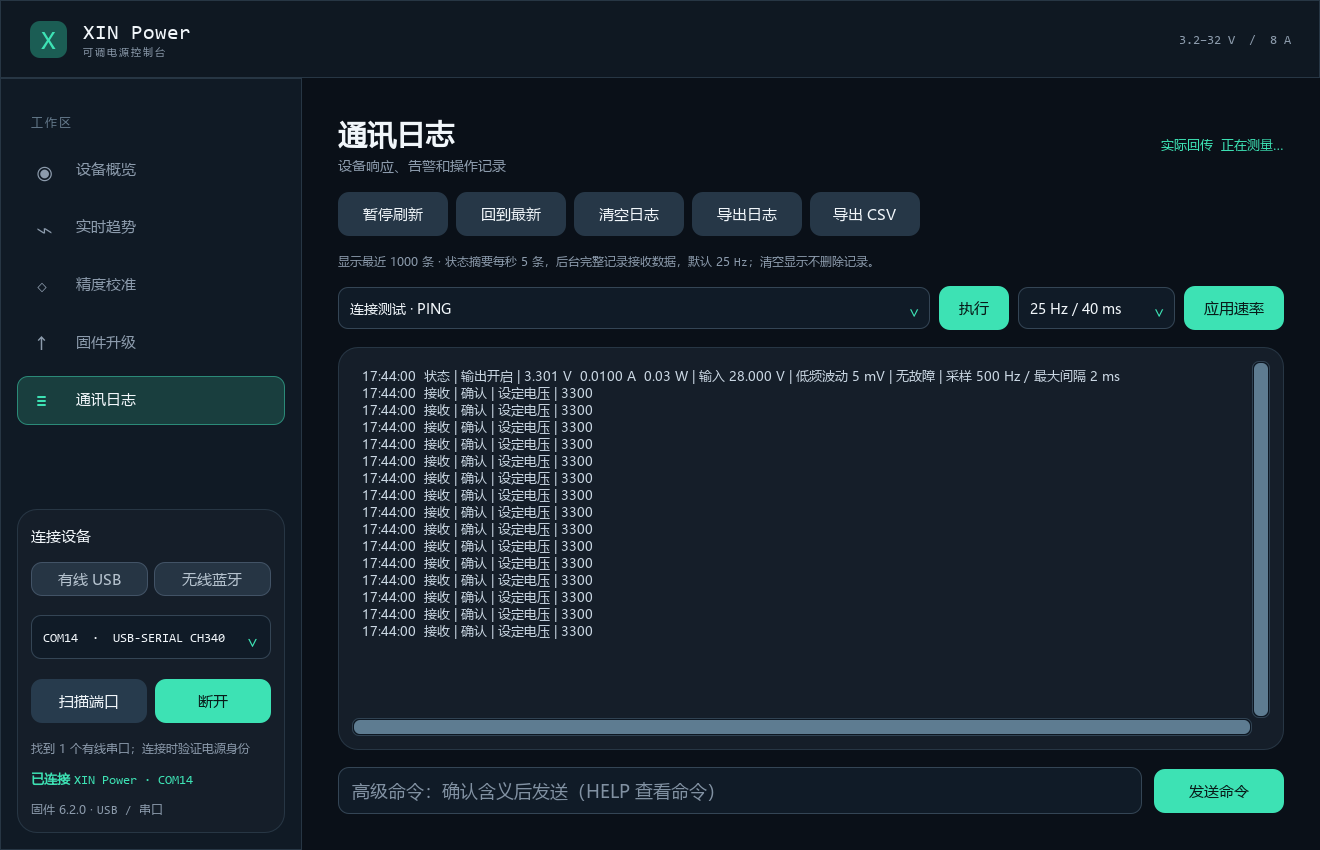
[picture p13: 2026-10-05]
firmware/current/05_PC_Tool/tests/page_620_4.png

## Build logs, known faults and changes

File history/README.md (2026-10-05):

# 历史关键版本

按版本升序提供源码快照和对应APP。早期节点有各自阻值/输出级/存储前提；“关键版本”表示可供比较的留存发布节点，不表示全部完成带载验收。

| 版本 | 源码 | 硬件前提与变化 |
|---|---|---|
| 5.9.3 | [XIN_Power_V5.9.3_PublicSource.zip](XIN_Power_V5.9.3_PublicSource.zip) | 原控制硬件；完整BL/APP/Factory/Recovery/PC；风扇与通信节点 |
| 6.0.4 | [XIN_Power_V6.0.4_PublicSource.zip](XIN_Power_V6.0.4_PublicSource.zip) | 当时原阻值/输出级；直接DAC校准及3.6V保存修复 |
| 6.0.8 | [XIN_Power_V6.0.8_PublicSource.zip](XIN_Power_V6.0.8_PublicSource.zip) | R316=4.99kΩ；当时输出级；SaveFix1_UIFix，直接DAC、Flash保存及回读修复 |
| 6.1.5 | [XIN_Power_V6.1.5_PublicSource.zip](XIN_Power_V6.1.5_PublicSource.zip) | R316=4.99kΩ；当时SRC补丁；匹配DAC参数，仍为2–32V/17点试验 |
| 6.2.2 | [XIN_Power_V6.2.2_PublicSource.zip](XIN_Power_V6.2.2_PublicSource.zip) | 当前V2旁路硬件；3.2–32V；纯DAC、休眠、25Hz、有线恢复 |

6.2.2为纯DAC对照；6.2.3当前完整工程含PI。公开历史源码补齐字体许可/资源，6.2.2换OFL中文位图后重新构建。原始与公开HASH见[manifest.json](manifest.json)，归档内部还包含逐文件SOURCE_SHA256和PUBLIC_SNAPSHOT说明。

本次从留存发布包重建索引，没有制造原始开发提交日期。6.0.8明确选SaveFix1_UIFix；中间诊断包和原始个人CSV/串口会话未上传。

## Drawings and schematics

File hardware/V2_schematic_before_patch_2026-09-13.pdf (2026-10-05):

# SNS2N 17 SNS2P 18 VOUT 19 BT2 20 HD2 21 SW2 22 LD2 23 VCC 24

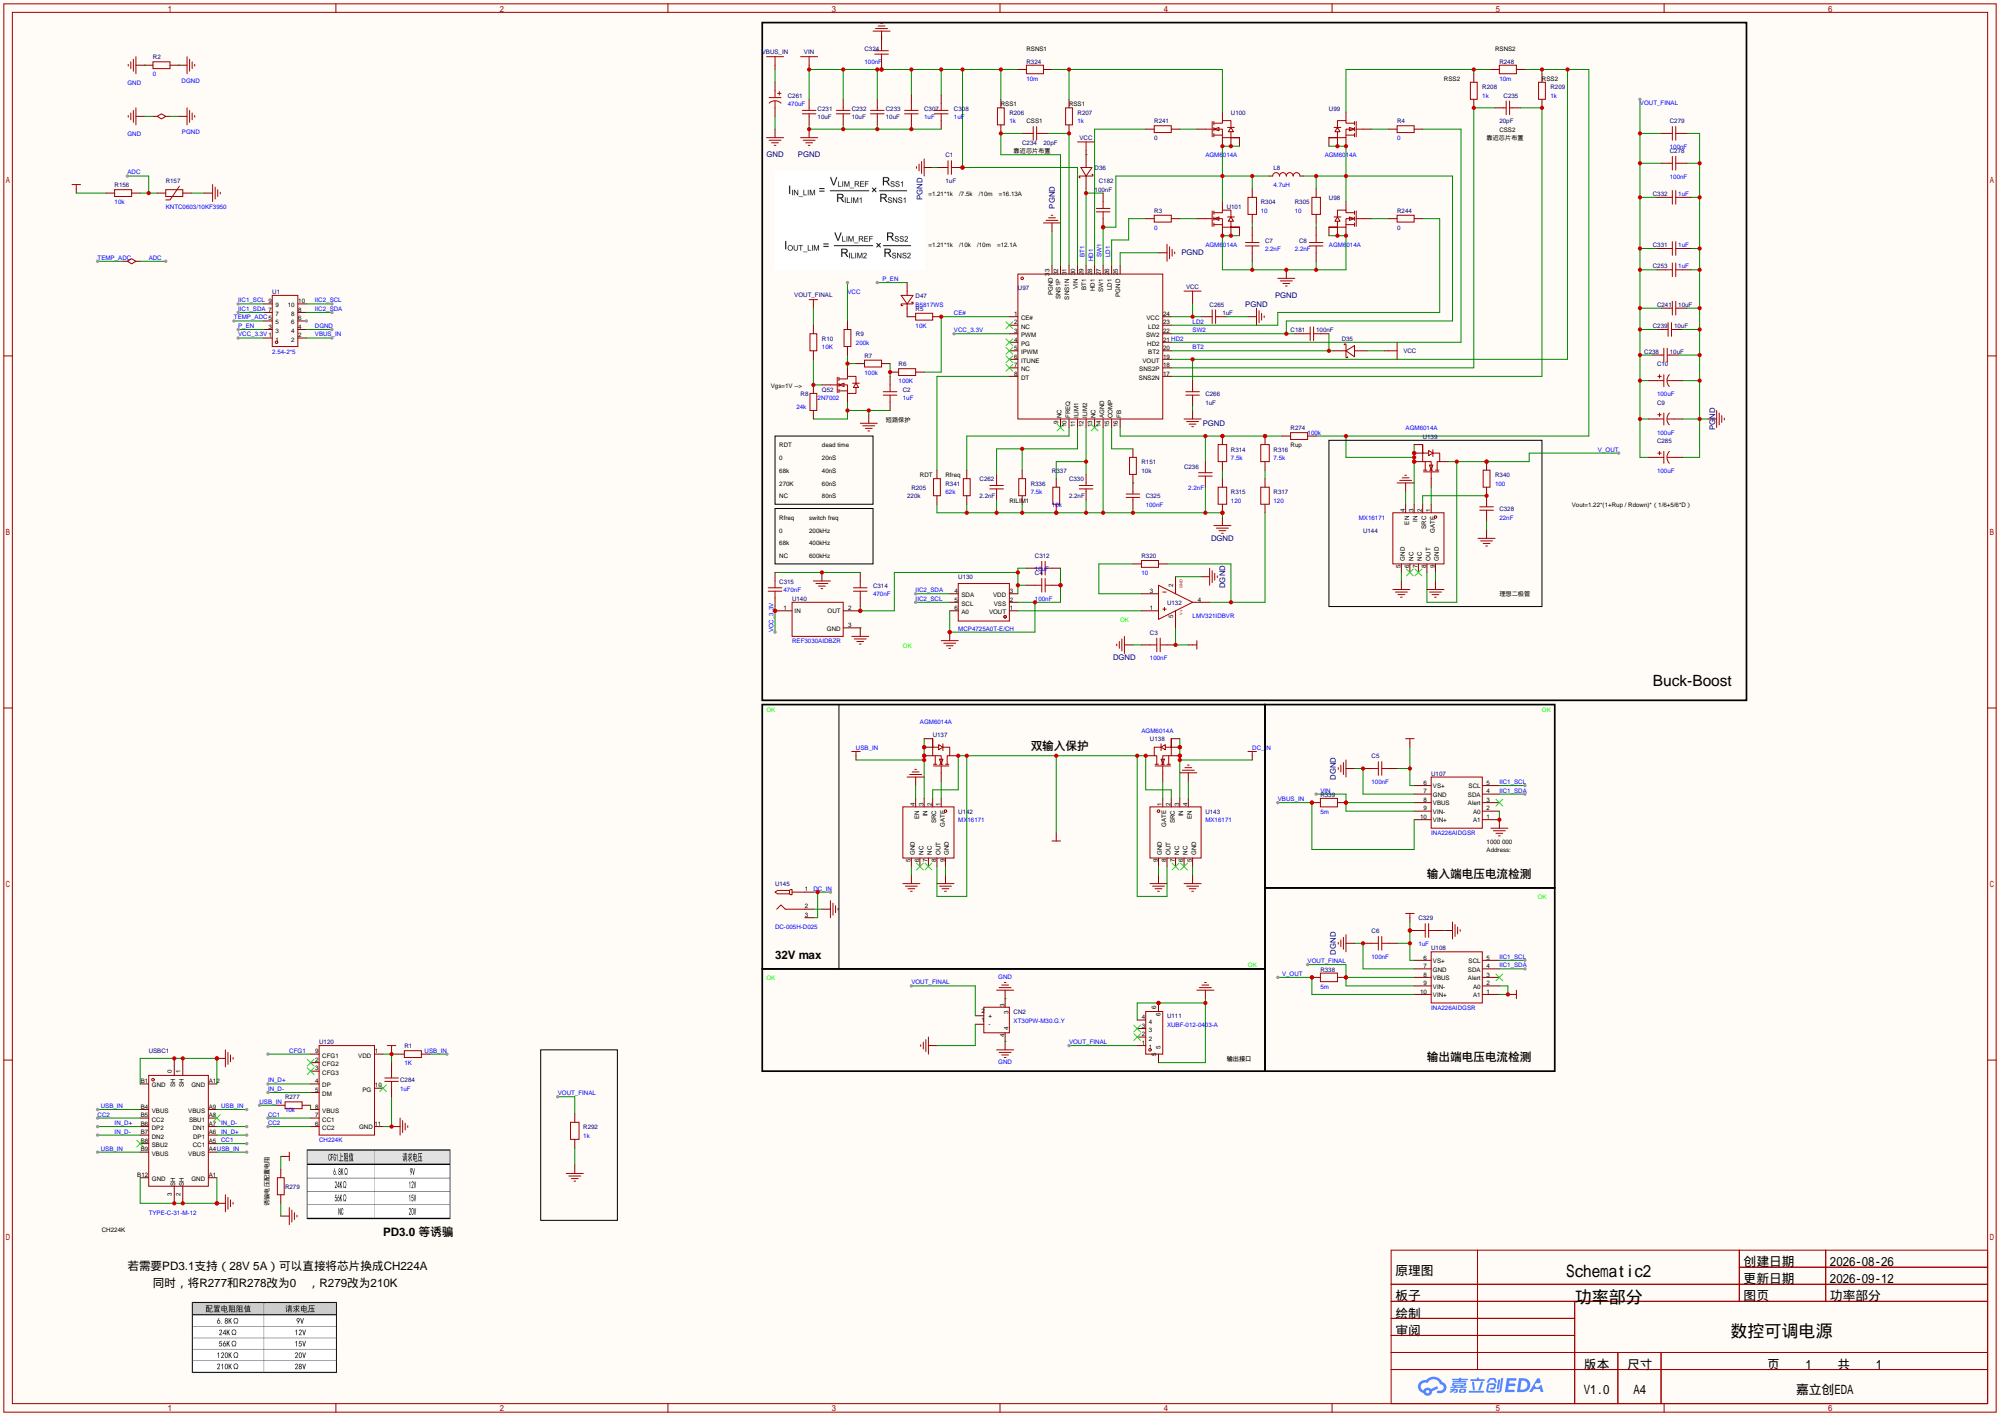
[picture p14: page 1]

原理图 | Schematic2 | 创建日期 | 2026-08-26

更新日期 | 2026-09-12

板子 | 功率部分 | 图页 | 功率部分
绘制 | | 数控可调电源
审阅

V1.0 | A4 | 嘉立创EDA

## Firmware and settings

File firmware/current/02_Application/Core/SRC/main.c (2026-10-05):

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

/* Includes ------------------------------------------------------------------*/
#include "main.h"
#include "rcc.h"
#include "gpio.h"
#include "dma.h"
#include "spi.h"
#include "tim.h"
#include "i2c.h"
#include "adc.h"
#include "usart.h"
/* USER CODE BEGIN Includes */
#include "cst836u.h"
#include "calibration.h"
#include "debug_console.h"
#include "fan_control.h"
#include "power_config.h"
#include "power_control.h"
#include "power_monitor.h"
#include "temperature_sensor.h"
#include "user_settings.h"
#include "lcd.h"
#include "ota_updater.h"
#include "splash_logo.h"
#include "ui_page.h"
#include <limits.h>
#include <stdio.h>
/* USER CODE END Includes */

/* USER CODE BEGIN PD */
#define APP_TOUCH_RECOVERY_PERIOD_MS       1000U
#define APP_NTC_DEBUG_PERIOD_MS            1000U
#define APP_CURRENT_PLAUSIBLE_MAX_UA      14000000L
#define APP_CURRENT_PLAUSIBLE_MIN_UA      (-2000000L)
#define APP_INPUT_PLAUSIBLE_MAX_MV          30000U
#define APP_OUTPUT_PLAUSIBLE_MAX_MV         34000U
#define APP_LOCAL_CALIBRATION_SAMPLE_COUNT      64U
#define APP_LOCAL_CALIBRATION_TIMEOUT_MS       3000U
#define APP_LOCAL_CALIBRATION_MAX_ZERO_UA     20000L
#define APP_LOCAL_CALIBRATION_MAX_SPAN_UA      8000L
#define APP_UI_CURRENT_ZERO_DEADBAND_UA         1000L

/* USER CODE END PD */

/* USER CODE BEGIN PV */
static bool s_touch_available = false;
static PowerMonitor_Snapshot_t s_power_snapshot;
static PowerControl_Status_t s_power_status;
static UI_ControlRequest_t s_control_request;
static PowerControl_Request_t s_power_request;
static TemperatureSensor_Snapshot_t s_temperature_snapshot;
static uint32_t s_last_touch_recovery_time_ms;
static uint32_t s_last_ntc_debug_time_ms;
static int64_t s_local_calibration_sum_ua;
static uint32_t s_local_calibration_start_time_ms;
static uint32_t s_local_calibration_last_sample_ms;
static uint32_t s_local_calibration_last_sequence;
static int32_t s_local_calibration_min_ua;
static int32_t s_local_calibration_max_ua;
static uint8_t s_local_calibration_sample_count;
static bool s_local_calibration_active;
static uint32_t s_reset_csr;
/* USER CODE END PV */

/* USER CODE BEGIN PFP */
static uint16_t App_CurrentUaToMa(int32_t current_ua);
static bool App_IsMeasurementPlausible(
  const PowerMonitor_Snapshot_t *measurement);
static void App_PrintResetCause(void);
static void App_ProcessLocalCalibration(uint32_t system_time_ms,
                                        bool measurement_updated);

/* USER CODE END PFP */

/* External functions --------------------------------------------------------*/
/* USER CODE BEGIN 0 */

/**
 * @brief  将INA226有符号微安值转换为UI使用的非负毫安值。
 * @param  current_ua INA226电流值，单位为微安。
 * @retval 四舍五入并限制范围后的毫安值。
 */
static uint16_t App_CurrentUaToMa(int32_t current_ua)
{
  uint32_t current_ma;

  if ((current_ua <= APP_UI_CURRENT_ZERO_DEADBAND_UA) ||
      (current_ua > APP_CURRENT_PLAUSIBLE_MAX_UA))
  {
    return 0U;
  }

  current_ma = ((uint32_t)current_ua + 500U) / 1000U;
  return (current_ma > UINT16_MAX) ? UINT16_MAX : (uint16_t)current_ma;
}

/** @brief 打印本次启动前由RCC保存的复位来源。 */
static void App_PrintResetCause(void)
{
  char text[192];

  (void)snprintf(text, sizeof(text),
                 "[RESET] csr=%08lX pin=%u power=%u soft=%u iwdg=%u wwdg=%u lowpower=%u option=%u\r\n",
                 (unsigned long)s_reset_csr,
                 (s_reset_csr & RCC_CSR_PINRSTF) ? 1U : 0U,
                 (s_reset_csr & RCC_CSR_PWRRSTF) ? 1U : 0U,
                 (s_reset_csr & RCC_CSR_SFTRSTF) ? 1U : 0U,
                 (s_reset_csr & RCC_CSR_IWDGRSTF) ? 1U : 0U,
                 (s_reset_csr & RCC_CSR_WWDGRSTF) ? 1U : 0U,
                 (s_reset_csr & RCC_CSR_LPWRRSTF) ? 1U : 0U,
                 (s_reset_csr & RCC_CSR_OBLRSTF) ? 1U : 0U);
  DebugConsole_Write(text);
}

/**
 * @brief  检查送往UI的数据是否处于本机硬件可能产生的范围。
 * @param  measurement 双路INA226测量快照。
 * @retval 数据完整且物理范围合理时返回true。
 * @note   该检查用于阻止损坏或错位数据绘制成58A等不可能数值，
 *         真正的输出保护仍由PowerControl完成。
 */
static bool App_IsMeasurementPlausible(
  const PowerMonitor_Snapshot_t *measurement)
{
  if ((measurement == NULL) || !measurement->data_valid)
  {
    return false;
  }

  return ((measurement->input_voltage_mv <= APP_INPUT_PLAUSIBLE_MAX_MV) &&
          (measurement->output_voltage_mv <= APP_OUTPUT_PLAUSIBLE_MAX_MV) &&
          (measurement->input_current_ua >= APP_CURRENT_PLAUSIBLE_MIN_UA) &&
          (measurement->input_current_ua <= APP_CURRENT_PLAUSIBLE_MAX_UA) &&
          (measurement->output_current_ua >= APP_CURRENT_PLAUSIBLE_MIN_UA) &&
          (measurement->output_current_ua <= APP_CURRENT_PLAUSIBLE_MAX_UA));
}

/**
 * @brief  每秒输出一次NTC原始值和换算温度，便于首板校准。
 * @param  system_time_ms 当前HAL毫秒计数值。
 * @retval 无。
 */


/**
 * @brief  执行本地输出电流零点自动校准。
 * @param  system_time_ms 当前HAL毫秒计数值。
 * @param  measurement_updated 本轮双INA226快照是否更新。
 * @retval 无。
 * @note   只在输出请求和真实输出均关闭时采集64帧未校准电流。
 */
static void App_ProcessLocalCalibration(uint32_t system_time_ms,
                                        bool measurement_updated)
{
  if (UI_TakeCurrentZeroCalibrationRequest())
  {
    if (s_control_request.output_requested || s_power_status.output_enabled ||
        UserSettings_IsSaving() || OtaUpdater_IsBusy() ||
        !s_power_snapshot.data_valid || !s_power_snapshot.output_online)
    {
      UI_SetCalibrationStatus(UI_CALIBRATION_FAILED);
    }
    else
    {
      s_local_calibration_sum_ua = 0;
      s_local_calibration_sample_count = 0U;
      s_local_calibration_min_ua = INT32_MAX;
      s_local_calibration_max_ua = INT32_MIN;
      s_local_calibration_last_sequence = s_power_snapshot.sample_sequence;
      s_local_calibration_start_time_ms = system_time_ms;
      s_local_calibration_last_sample_ms = system_time_ms;
      s_local_calibration_active = true;
      UI_SetCalibrationStatus(UI_CALIBRATION_RUNNING);
      DebugConsole_Write("[CAL] local current-zero sampling started\r\n");
    }
  }

  if (!s_local_calibration_active)
  {
    return;
  }
  if (s_control_request.output_requested || s_power_status.output_enabled ||
      ((system_time_ms - s_local_calibration_start_time_ms) >=
       APP_LOCAL_CALIBRATION_TIMEOUT_MS))
  {
    s_local_calibration_active = false;
    UI_SetCalibrationStatus(UI_CALIBRATION_FAILED);
    DebugConsole_Write("[CAL] local current-zero aborted\r\n");
    return;
  }

  if (measurement_updated && s_power_snapshot.data_valid &&
      (system_time_ms - s_local_calibration_last_sample_ms >= 20U) &&
      (s_power_snapshot.sample_sequence != s_local_calibration_last_sequence))
  {
    int32_t raw_zero_ua = s_power_snapshot.output_current_uncalibrated_ua;
    int32_t absolute_zero_ua = (raw_zero_ua < 0) ? -raw_zero_ua : raw_zero_ua;

    s_local_calibration_last_sequence = s_power_snapshot.sample_sequence;
    s_local_calibration_last_sample_ms = system_time_ms;
    if (absolute_zero_ua > APP_LOCAL_CALIBRATION_MAX_ZERO_UA)
    {
      s_local_calibration_active = false;
      UI_SetCalibrationStatus(UI_CALIBRATION_FAILED);
      DebugConsole_Write("[CAL] local current-zero rejected: load detected\r\n");
      return;
    }
    if (raw_zero_ua < s_local_calibration_min_ua)
    {
      s_local_calibration_min_ua = raw_zero_ua;
    }
    if (raw_zero_ua > s_local_calibration_max_ua)
    {
      s_local_calibration_max_ua = raw_zero_ua;
    }
    s_local_calibration_sum_ua += raw_zero_ua;
    s_local_calibration_sample_count++;
    if (s_local_calibration_sample_count >=
        APP_LOCAL_CALIBRATION_SAMPLE_COUNT)
    {
      int32_t average_zero_ua = (int32_t)(
        s_local_calibration_sum_ua / APP_LOCAL_CALIBRATION_SAMPLE_COUNT);
      int32_t sample_span_ua = s_local_calibration_max_ua -
                               s_local_calibration_min_ua;
      bool saved = (sample_span_ua <= APP_LOCAL_CALIBRATION_MAX_SPAN_UA) &&
                   Calibration_SaveCurrentZero(average_zero_ua);

      s_local_calibration_active = false;
      UI_SetCalibrationStatus(saved ? UI_CALIBRATION_SAVED :
                                        UI_CALIBRATION_FAILED);
      DebugConsole_Write(saved ?
        "[CAL] local current-zero saved to W25Q256\r\n" :
        "[CAL] local current-zero save failed\r\n");
    }
  }
}

/* USER CODE END 0 */

/**
  * @brief  The application entry point.
  * @retval int
  */
static bool s_power_service_ready, s_power_service_busy, s_fast_measurement_pending;

/* Foreground only: LCD yields between bounded transfers and canvas rows.
 * No I2C/formatting/UI work is added to interrupt handlers. */
void LCD_BackgroundService(void)
{
  if (!s_power_service_ready || s_power_service_busy) { return; }
  s_power_service_busy = true;
  PowerControl_Status_t ripple_status;
  PowerControl_GetStatus(&ripple_status);
  PowerMonitor_SetRippleContext(ripple_status.output_enabled,
                                PowerControl_GetRippleDacCode(), HAL_GetTick());
  PowerMonitor_Process(HAL_GetTick());
  s_fast_measurement_pending |= PowerMonitor_GetSnapshot(&s_power_snapshot);
  PowerControl_ServiceProtections(HAL_GetTick(), &s_power_request, &s_power_snapshot);
  PowerControl_ServiceVoltageTrim(HAL_GetTick(), &s_power_request, &s_power_snapshot);
  s_power_service_busy = false;
}

void PowerMonitor_OnCurrentSample(bool output, int32_t calibrated_ua,
  int32_t uncalibrated_ua, uint16_t voltage_mv, uint32_t now)
{
  if (!s_power_service_ready) { return; }
  PowerControl_ServiceCurrentSample(now,output,calibrated_ua,uncalibrated_ua,
    voltage_mv,&s_power_request,&s_power_snapshot);
}

int main(void)
{
  /* USER CODE BEGIN 1 */
  s_reset_csr = RCC->CSR;
  __HAL_RCC_CLEAR_RESET_FLAGS();

  /* USER CODE END 1 */
  /* MCU Configuration--------------------------------------------------------*/

  /* Reset of all peripherals, Initializes the Flash interface and the Systick. */
  HAL_Init();
  /* Configure the system clock */
  Studio_RCC_Init();
  /* Initialize all configured peripherals */
  Studio_GPIO_Init();
  /* Fail-safe output gate is asserted before any peripheral probing. */
  HAL_GPIO_WritePin(P_EN_Port, P_EN_Pin, GPIO_PIN_SET);
  Studio_DMA_Init();
  Studio_SPI1_Init();
  Studio_TIM1_Init();
  Studio_I2C1_Init();
  Studio_I2C2_Init();
  Studio_ADC1_Init();
  Studio_TIM2_Init();
  Studio_TIM3_Init();
  Studio_SPI2_Init();
  Studio_USART1_Init();
  Studio_USART2_Init();
  /* USER CODE BEGIN 2 */
  /* 先从W25Q256双备份区装载校准参数，再启动采样和DAC控制。 */
  Calibration_Init();
  UserSettings_Init();
  /* 先启动双串口接收，后续初始化日志即可同时从USB和蓝牙查看。 */
  (void)DebugConsole_Init();
  App_PrintResetCause();
  if (!FanControl_Init())
  {
    DebugConsole_Write("[FAN] PWM start failed\r\n");
  }
  /* 所有监测与DAC初始化完成前，始终保持真实功率输出关闭。 */
  HAL_GPIO_WritePin(P_EN_Port, P_EN_Pin, GPIO_PIN_SET);

  if (!LCD_Init())
  {
    Error_Handler();
  }

  s_touch_available = CST836U_Init();
  (void)PowerMonitor_Init();
  (void)TemperatureSensor_Init(HAL_GetTick());
  (void)TemperatureSensor_GetSnapshot(&s_temperature_snapshot);
  (void)PowerControl_Init();
  if (!s_touch_available)
  {
    /* 初次探测失败时在总线初始化完成后立即补探一次。 */
    s_touch_available = CST836U_TryRecover();
  }
  /* The supplied logo is shown for one second after all normal probing. */
  SplashLogo_Draw();
  HAL_Delay(1000U);
  /* 耗时的I2C扫描结束后再启动UI防误触计时，避免保护窗口提前耗尽。 */
  UI_Init(s_touch_available);
  {
    UserSettings_Data_t saved_settings;
    UserSettings_Get(&saved_settings);
    if (saved_settings.loaded_from_flash)
    {
      (void)UI_SetVoltageSetpoint(saved_settings.voltage_setpoint_mv);
      (void)UI_SetCurrentLimit(saved_settings.current_limit_ma);
      (void)UI_SetScreenSleepSeconds(saved_settings.screen_sleep_seconds);
      DebugConsole_Write("[SETTINGS] restored voltage/current setpoints\r\n");
    }
  }
  /* Start the unchanged OTA trial/confirmation flow. */
  OtaUpdater_StartTrial(HAL_GetTick());
  s_last_touch_recovery_time_ms = HAL_GetTick();
  s_last_ntc_debug_time_ms = HAL_GetTick();
  s_local_calibration_active = false;
  s_power_service_ready = true;
  /* USER CODE END 2 */

  /* Infinite loop */
  /* USER CODE BEGIN WHILE */
  while(1)
  {
    /* USER CODE END WHILE */
    /* USER CODE BEGIN 3 */
    uint32_t system_time_ms = HAL_GetTick();
    uint16_t output_current_ma;
    bool measurement_updated;
    bool touch_ready;

    LCD_BackgroundService();
    DebugConsole_Service(system_time_ms);

    /* 触摸初始化偶发失败或运行中掉线时，每秒低频探测一次并同步UI。 */
    touch_ready = CST836U_IsReady();
    if (!touch_ready &&
        ((system_time_ms - s_last_touch_recovery_time_ms) >=
         APP_TOUCH_RECOVERY_PERIOD_MS))
    {
      s_last_touch_recovery_time_ms = system_time_ms;
      touch_ready = CST836U_TryRecover();
    }
    if (touch_ready != s_touch_available)
    {
      s_touch_available = touch_ready;
      UI_SetTouchAvailable(s_touch_available);
    }

    /* Sampling/current shutdown have already run before touch on shared I2C1. */
    UI_ProcessInput(system_time_ms);
    if (OtaUpdater_IsBusy())
    {
      UI_ForceOutputOff();
    }
    /* 页面重绘使用同步SPI，后续控制周期必须取实际时间而非绘制前时间。 */
    system_time_ms = HAL_GetTick();
    (void)TemperatureSensor_Process(system_time_ms);
    (void)TemperatureSensor_GetSnapshot(&s_temperature_snapshot);
    LCD_BackgroundService();
    measurement_updated = s_fast_measurement_pending;
    s_fast_measurement_pending = false;
    /* Apply remote OUT/SET requests in this control pass, not after drawing. */
    DebugConsole_Process(HAL_GetTick(), &s_power_snapshot,
                         &s_power_status, &s_temperature_snapshot);
    system_time_ms = HAL_GetTick();
    UI_GetControlRequest(&s_control_request);
    FanControl_Update(s_temperature_snapshot.temperature_decic,
                      s_temperature_snapshot.valid);
    if (UI_TakeFaultClearRequest())
    {
      (void)PowerControl_ClearFault();
      UI_SetPowerFault(false);
    }
    s_power_request.voltage_setpoint_mv = s_control_request.voltage_setpoint_mv;
    s_power_request.current_limit_ma = s_control_request.current_limit_ma;
    s_power_request.temperature_decic =
      s_temperature_snapshot.temperature_decic;
    s_power_request.temperature_valid = s_temperature_snapshot.valid;
    s_power_request.output_requested = s_control_request.output_requested &&
                                       !OtaUpdater_IsBusy();
    PowerControl_Process(system_time_ms,
                         &s_power_request,
                         &s_power_snapshot);
    PowerControl_GetStatus(&s_power_status);
    UI_SetPowerFault(s_power_status.fault != POWER_CONTROL_FAULT_NONE);
    App_ProcessLocalCalibration(system_time_ms, measurement_updated);

    (void)UserSettings_SetScreenSleepSeconds(s_control_request.screen_sleep_seconds,
                                            system_time_ms);
    if (UserSettings_Process(s_control_request.voltage_setpoint_mv,
                             s_control_request.current_limit_ma,
                             system_time_ms,
                             !s_control_request.output_requested &&
                             !s_power_status.output_enabled &&
                             !s_local_calibration_active && !OtaUpdater_IsBusy()))
    {
      DebugConsole_Write("[SETTINGS] voltage/current setpoints saved\r\n");
    }

    if (s_power_status.fault != POWER_CONTROL_FAULT_NONE)
    {
      UI_ForceOutputOff();
    }

    if (measurement_updated &&
        App_IsMeasurementPlausible(&s_power_snapshot))
    {
      output_current_ma = App_CurrentUaToMa(s_power_snapshot.output_current_ua);

      UI_SetMeasurements(s_power_snapshot.input_voltage_mv,
                         s_power_snapshot.output_voltage_mv,
                         output_current_ma,
                         s_power_snapshot.output_power_mw,
                         s_temperature_snapshot.temperature_decic,
                         s_power_status.constant_current);
      UI_SetRipple(s_power_snapshot.ripple_vpp_mv,s_power_snapshot.ripple_valid);
    }


    if (!UserSettings_IsSaving())
    {
    OtaUpdater_Process(HAL_GetTick(),
                       (s_power_status.fault == POWER_CONTROL_FAULT_NONE));
    }
    UI_Render(HAL_GetTick());
  }
  /* USER CODE END 3 */
}

/* USER CODE BEGIN 4 */

/**
 * @brief  HAL GPIO外部中断回调函数。
 * @param  GPIO_Pin HAL EXTI处理程序上报的引脚掩码。
 * @retval 无。
 */
void HAL_GPIO_EXTI_Callback(uint16_t GPIO_Pin)
{
  if (GPIO_Pin == TP_INT_Pin)
  {
    CST836U_NotifyInterrupt();
  }
}

/* USER CODE END 4 */
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


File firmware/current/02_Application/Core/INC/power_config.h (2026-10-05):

/**
  ******************************************************************************
  * @file    power_config.h
  * @brief   数控电源量程、保护阈值和FB调压参数集中配置。
  ******************************************************************************
  */

#ifndef __POWER_CONFIG_H__
#define __POWER_CONFIG_H__

/* 用户可调范围。 */
#define POWER_CFG_VOLTAGE_MIN_MV              3200U
#define POWER_CFG_VOLTAGE_MAX_MV             32000U
#define POWER_CFG_CURRENT_MIN_MA                100U
#define POWER_CFG_CURRENT_MAX_MA               8000U

/* Short-circuit overcurrent uses these SAME immediate current trips.
 * No independent low-voltage, small-current or startup-delay short detector. */
#define POWER_CFG_INPUT_TRIP_MA                 4800U
#define POWER_CFG_OUTPUT_TRIP_MA                8500U

/* 功率区NTC与风扇。 */
#define POWER_CFG_FAN_START_DEFAULT_C                40U
#define POWER_CFG_FAN_STOP_C                         35U
#define POWER_CFG_OUTPUT_BLEEDER_OHM               1800U
#define POWER_CFG_FAN_START_MIN_C                    30U
#define POWER_CFG_FAN_START_MAX_C                    65U
#define POWER_CFG_FAN_START_STEP_C                    1U

/* SC8701 FB网络和MCP4725参考电压。 */
#define POWER_CFG_FB_REFERENCE_UV            1220000UL
#define POWER_CFG_DAC_REFERENCE_UV           3000000UL
#define POWER_CFG_FB_UPPER_OHM                100000UL
#define POWER_CFG_FB_LOWER_OHM                  7620UL

/* R274=100k, R314+R315=7.62k, R316+R317=4.99k+120=5.11k. */
#define POWER_CFG_FB_INJECTION_OHM              5110UL
#define POWER_CFG_DAC_SCALE_CODES               4096UL
#define POWER_CFG_SAMPLE_PERIOD_MS                2U
#define POWER_CFG_DAC_HARDWARE_TAG             0x4991U

#define POWER_CFG_INPUT_UV_MV                   4000U
#define POWER_CFG_INPUT_UV_DELAY_MS               200U
#define POWER_CFG_OUTPUT_ABSOLUTE_OV_MV         33000U
#define POWER_CFG_OUTPUT_OV_MARGIN_MV             300U
#define POWER_CFG_OUTPUT_OV_PERMILLE              100U
/* C9+C10+C285=300uF, C238+C239+C241=30uF, bypasses ~3uF.
 * 400uF covers nominal capacitance plus 20% tolerance. R292 is confirmed
 * fitted as 1.8k, giving a conservative 720ms RC time constant. */
#define POWER_CFG_OUTPUT_DISCHARGE_CAP_UF         400U
#define POWER_CFG_OUTPUT_DISCHARGE_TAU_MS \
  ((POWER_CFG_OUTPUT_BLEEDER_OHM * POWER_CFG_OUTPUT_DISCHARGE_CAP_UF + 999U) / 1000U)
#define POWER_CFG_OUTPUT_OV_DELAY_MS              100U
#define POWER_CFG_OVER_TEMPERATURE_DECIC          800
#define POWER_CFG_MONITOR_LOSS_MIN_MS             500U
#define POWER_CFG_MONITOR_LOSS_PERIODS              3U

/* Small-error outer voltage loop: PI (D=0), per fresh 2ms sample.
 * +/-100mV is the observation gate, NOT a total compensation limit.
 * Coefficients are trial defaults pending measured load-step tuning. */
#define POWER_CFG_TRIM_BAND_MV                 100L
#define POWER_CFG_TRIM_DEADBAND_MV               8L
#define POWER_CFG_TRIM_KP                       0.20f
#define POWER_CFG_TRIM_KI_PER_SECOND            2.00f
#define POWER_CFG_TRIM_MAX_SAMPLE_GAP_MS         20U
#define POWER_CFG_TRIM_DAC_INTERVAL_MS           10U
#endif /* __POWER_CONFIG_H__ */

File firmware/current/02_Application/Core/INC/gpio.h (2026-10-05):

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

/* Define to prevent recursive inclusion -------------------------------------*/
#ifndef __GPIO_H__
#define __GPIO_H__

#ifdef __cplusplus
extern "C" {
#endif

/* Includes ------------------------------------------------------------------*/
#include "main.h"
#define LCD_CS_Pin GPIO_PIN_4
#define LCD_CS_Port GPIOA
#define LCD_DC_Pin GPIO_PIN_0
#define LCD_DC_Port GPIOB
#define LCD_RST_Pin GPIO_PIN_1
#define LCD_RST_Port GPIOB
#define TP_INT_Pin GPIO_PIN_8
#define TP_INT_Port GPIOB
#define TP_RST_Pin GPIO_PIN_9
#define TP_RST_Port GPIOB
#define FLA_CS_Pin GPIO_PIN_12
#define FLA_CS_Port GPIOB
#define P_EN_Pin GPIO_PIN_13
#define P_EN_Port GPIOC

void Studio_GPIO_Init(void);


#ifdef __cplusplus
}
#endif

#endif /* __GPIO_H__ */

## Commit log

2026-10-05 archive: preserve V6.0.4 direct DAC calibration milestone
2026-10-05 publish: add complete V6.2.3 open project, documentation, hardware and verified Windows download parts
    [XIN_Power外壳.step, XIN_Power外壳上.step, XIN_Power外壳下.3mf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]
2026-10-11 docs: sync author revision, schematics and 95W load test records
2026-10-11 docs: keep latest replication guide and remove superseded materials

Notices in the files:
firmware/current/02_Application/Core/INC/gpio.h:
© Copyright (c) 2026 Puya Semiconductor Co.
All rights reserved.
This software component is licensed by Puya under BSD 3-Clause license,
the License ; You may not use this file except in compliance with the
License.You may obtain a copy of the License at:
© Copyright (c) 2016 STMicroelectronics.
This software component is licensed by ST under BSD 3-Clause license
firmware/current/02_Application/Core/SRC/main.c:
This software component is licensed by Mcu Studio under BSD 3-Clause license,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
